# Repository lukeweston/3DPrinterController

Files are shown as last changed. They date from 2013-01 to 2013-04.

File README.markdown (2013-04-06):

3D printer / CNC machine controller:   

The final system will be broken across three boards, to allow for modularity, replacement of the modules individually, upgradability, and to allow enough space for proper
design of the power electronics.   

a) Microcontroller, UI, storage, display, connectivity etc.   
b) Power distribution, switching, heater control etc.   
c) Stepper motor drivers.   

Example image of 5-channel stepper motor controller board:   

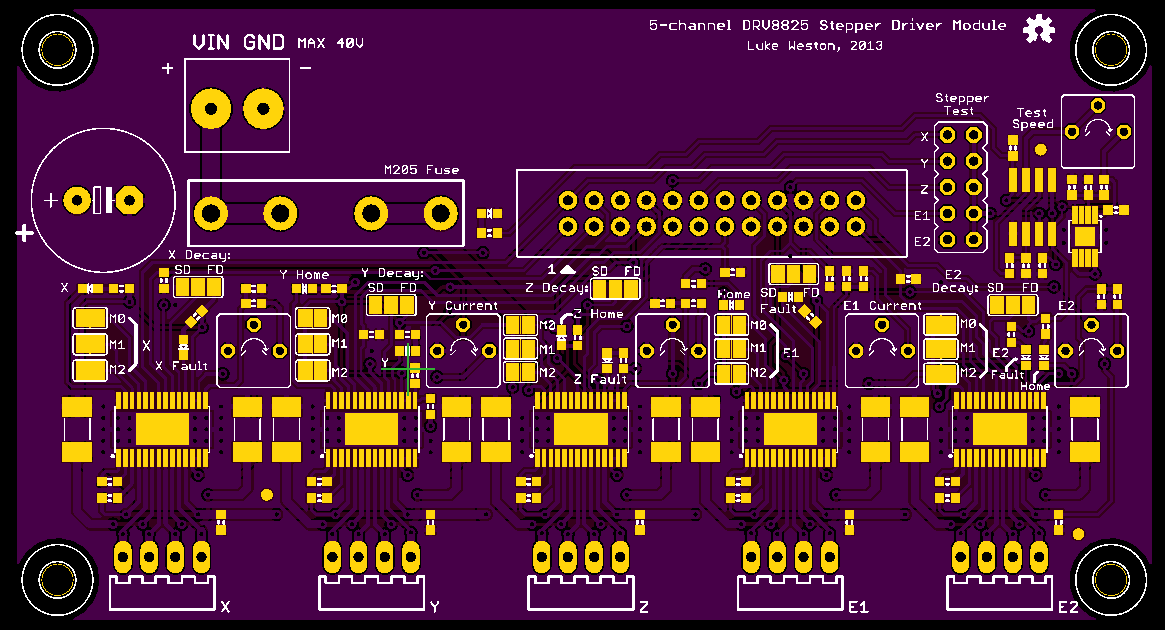
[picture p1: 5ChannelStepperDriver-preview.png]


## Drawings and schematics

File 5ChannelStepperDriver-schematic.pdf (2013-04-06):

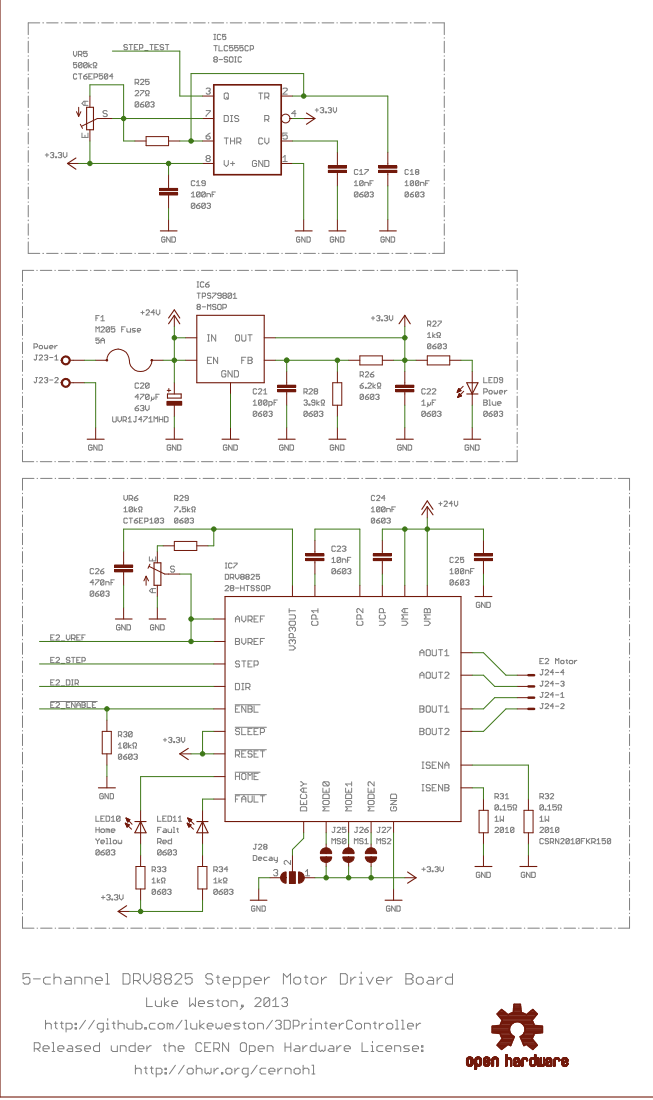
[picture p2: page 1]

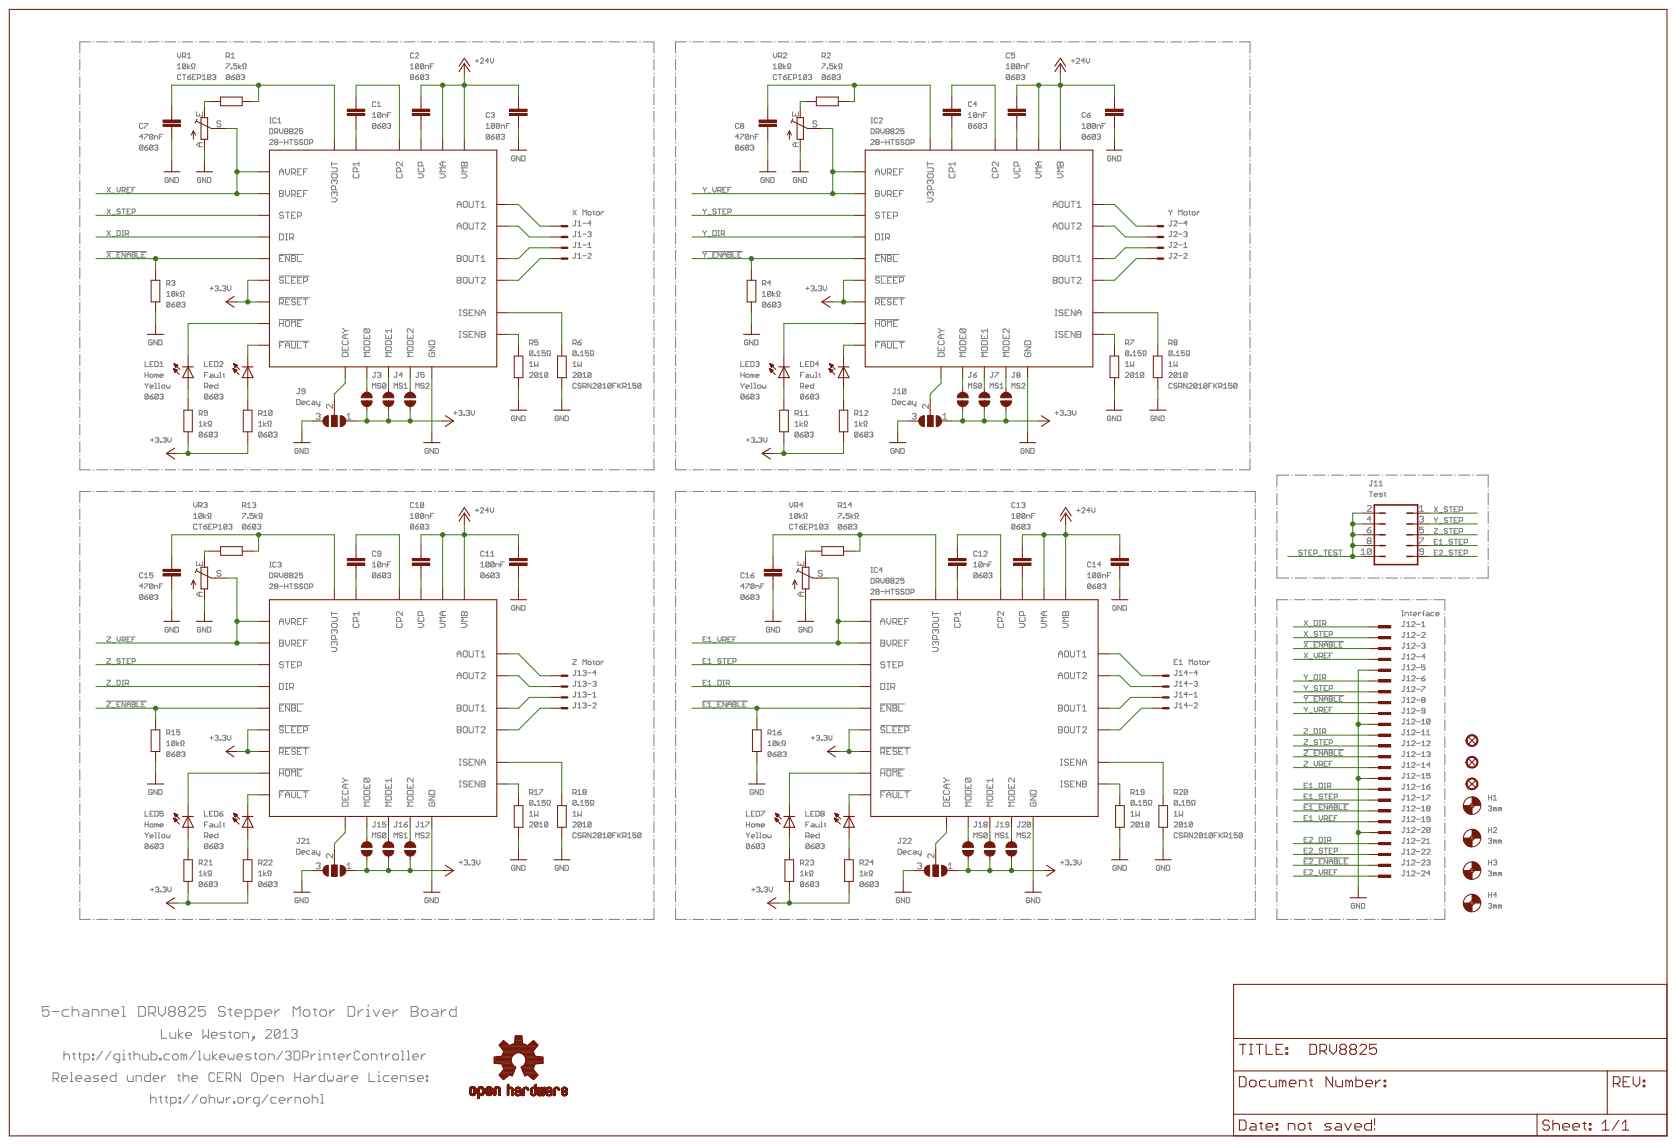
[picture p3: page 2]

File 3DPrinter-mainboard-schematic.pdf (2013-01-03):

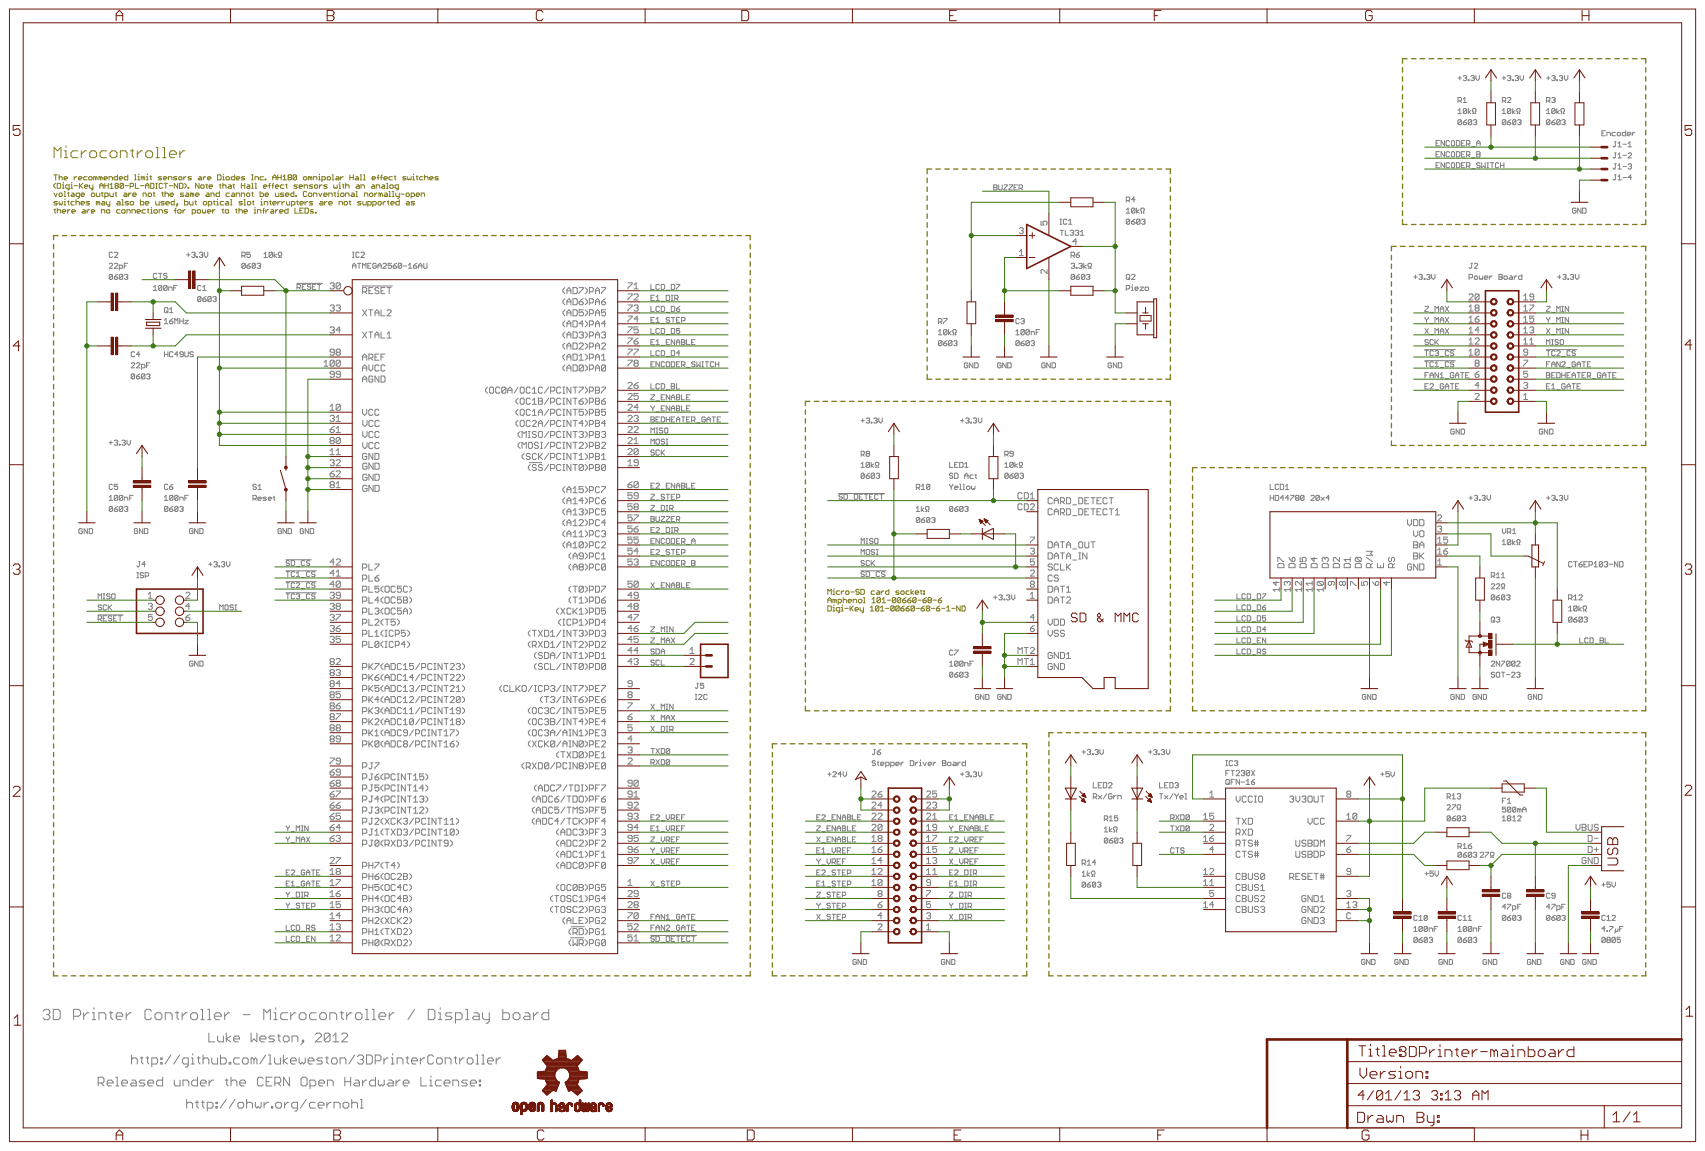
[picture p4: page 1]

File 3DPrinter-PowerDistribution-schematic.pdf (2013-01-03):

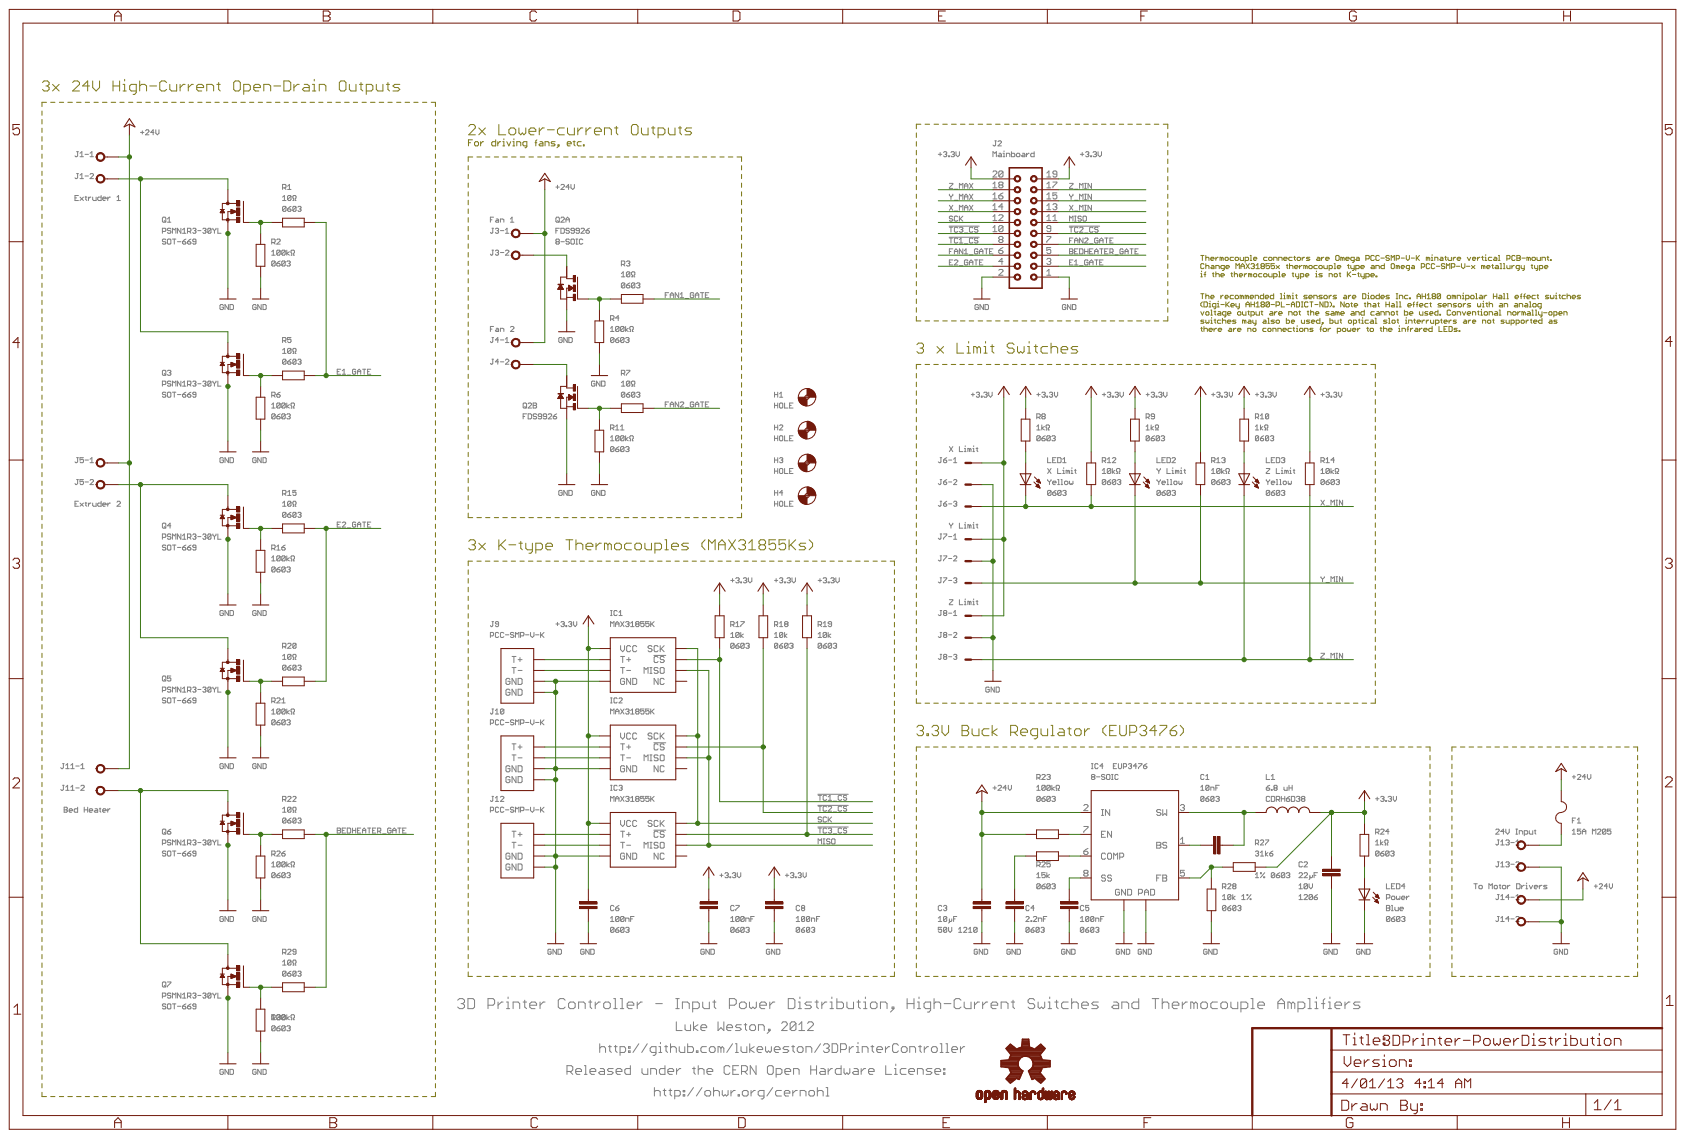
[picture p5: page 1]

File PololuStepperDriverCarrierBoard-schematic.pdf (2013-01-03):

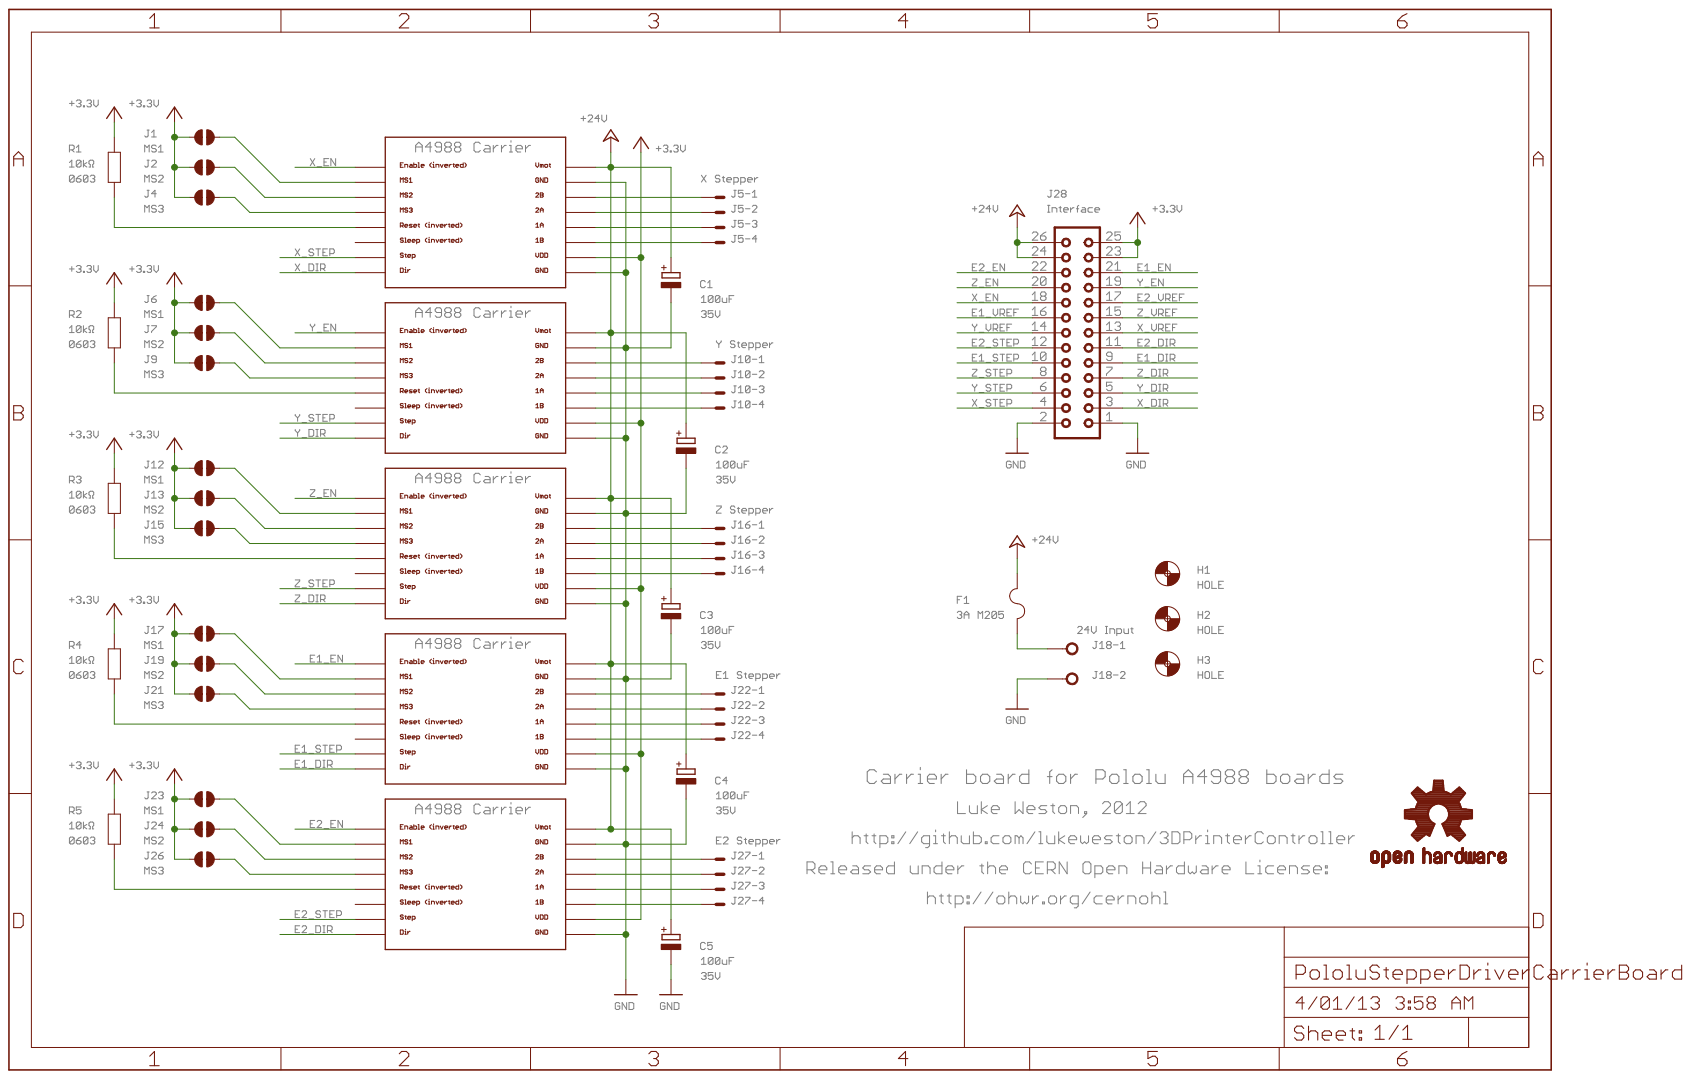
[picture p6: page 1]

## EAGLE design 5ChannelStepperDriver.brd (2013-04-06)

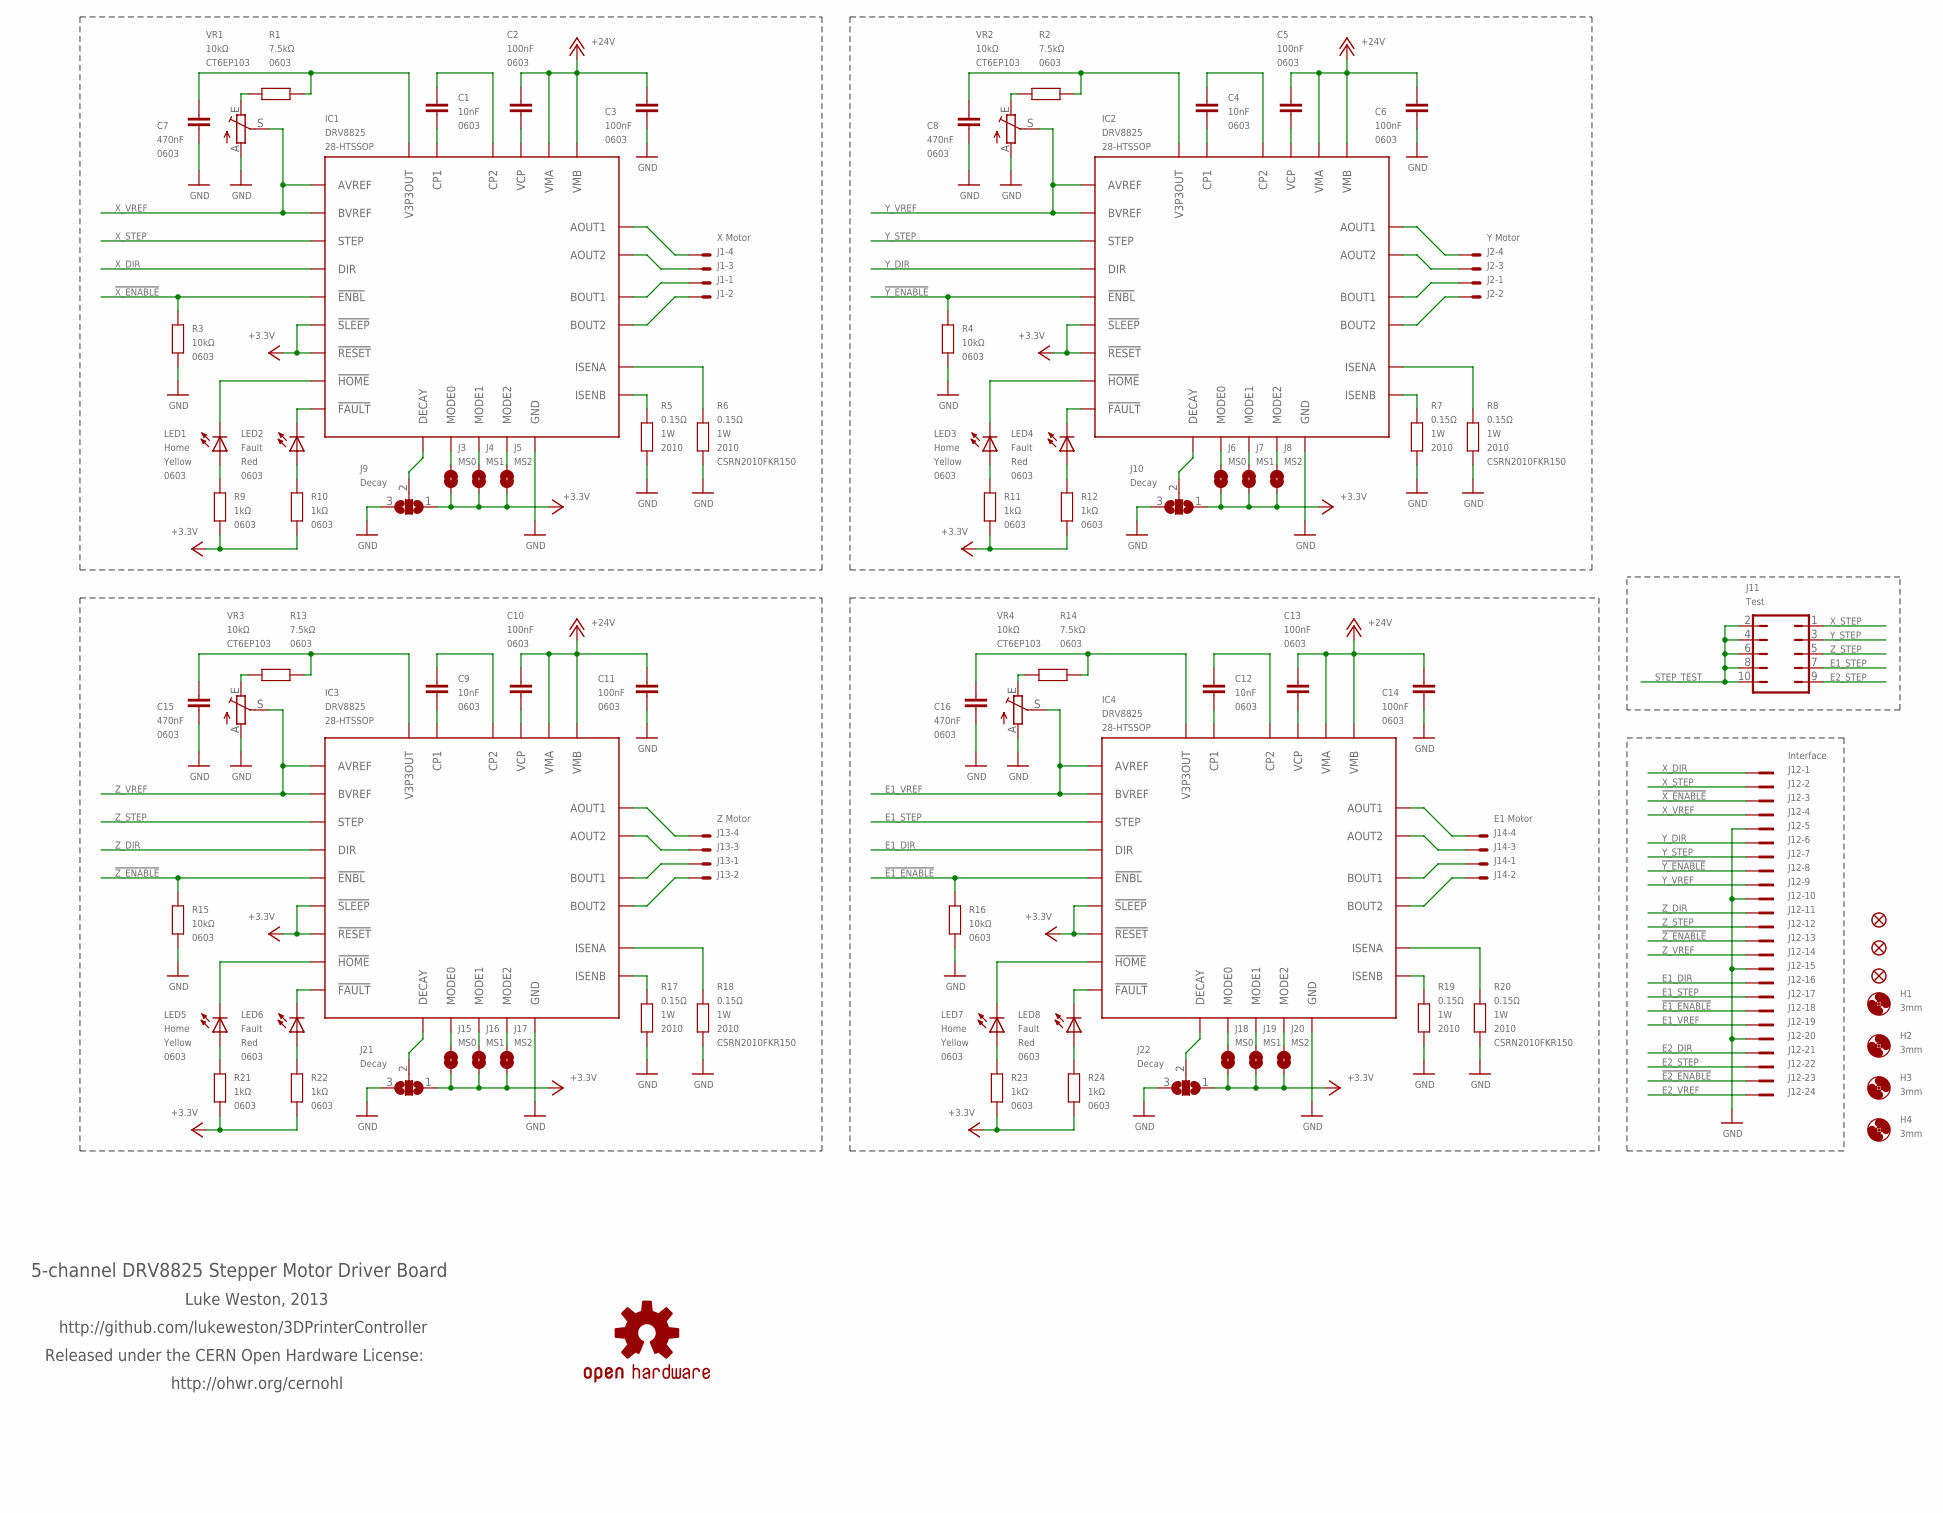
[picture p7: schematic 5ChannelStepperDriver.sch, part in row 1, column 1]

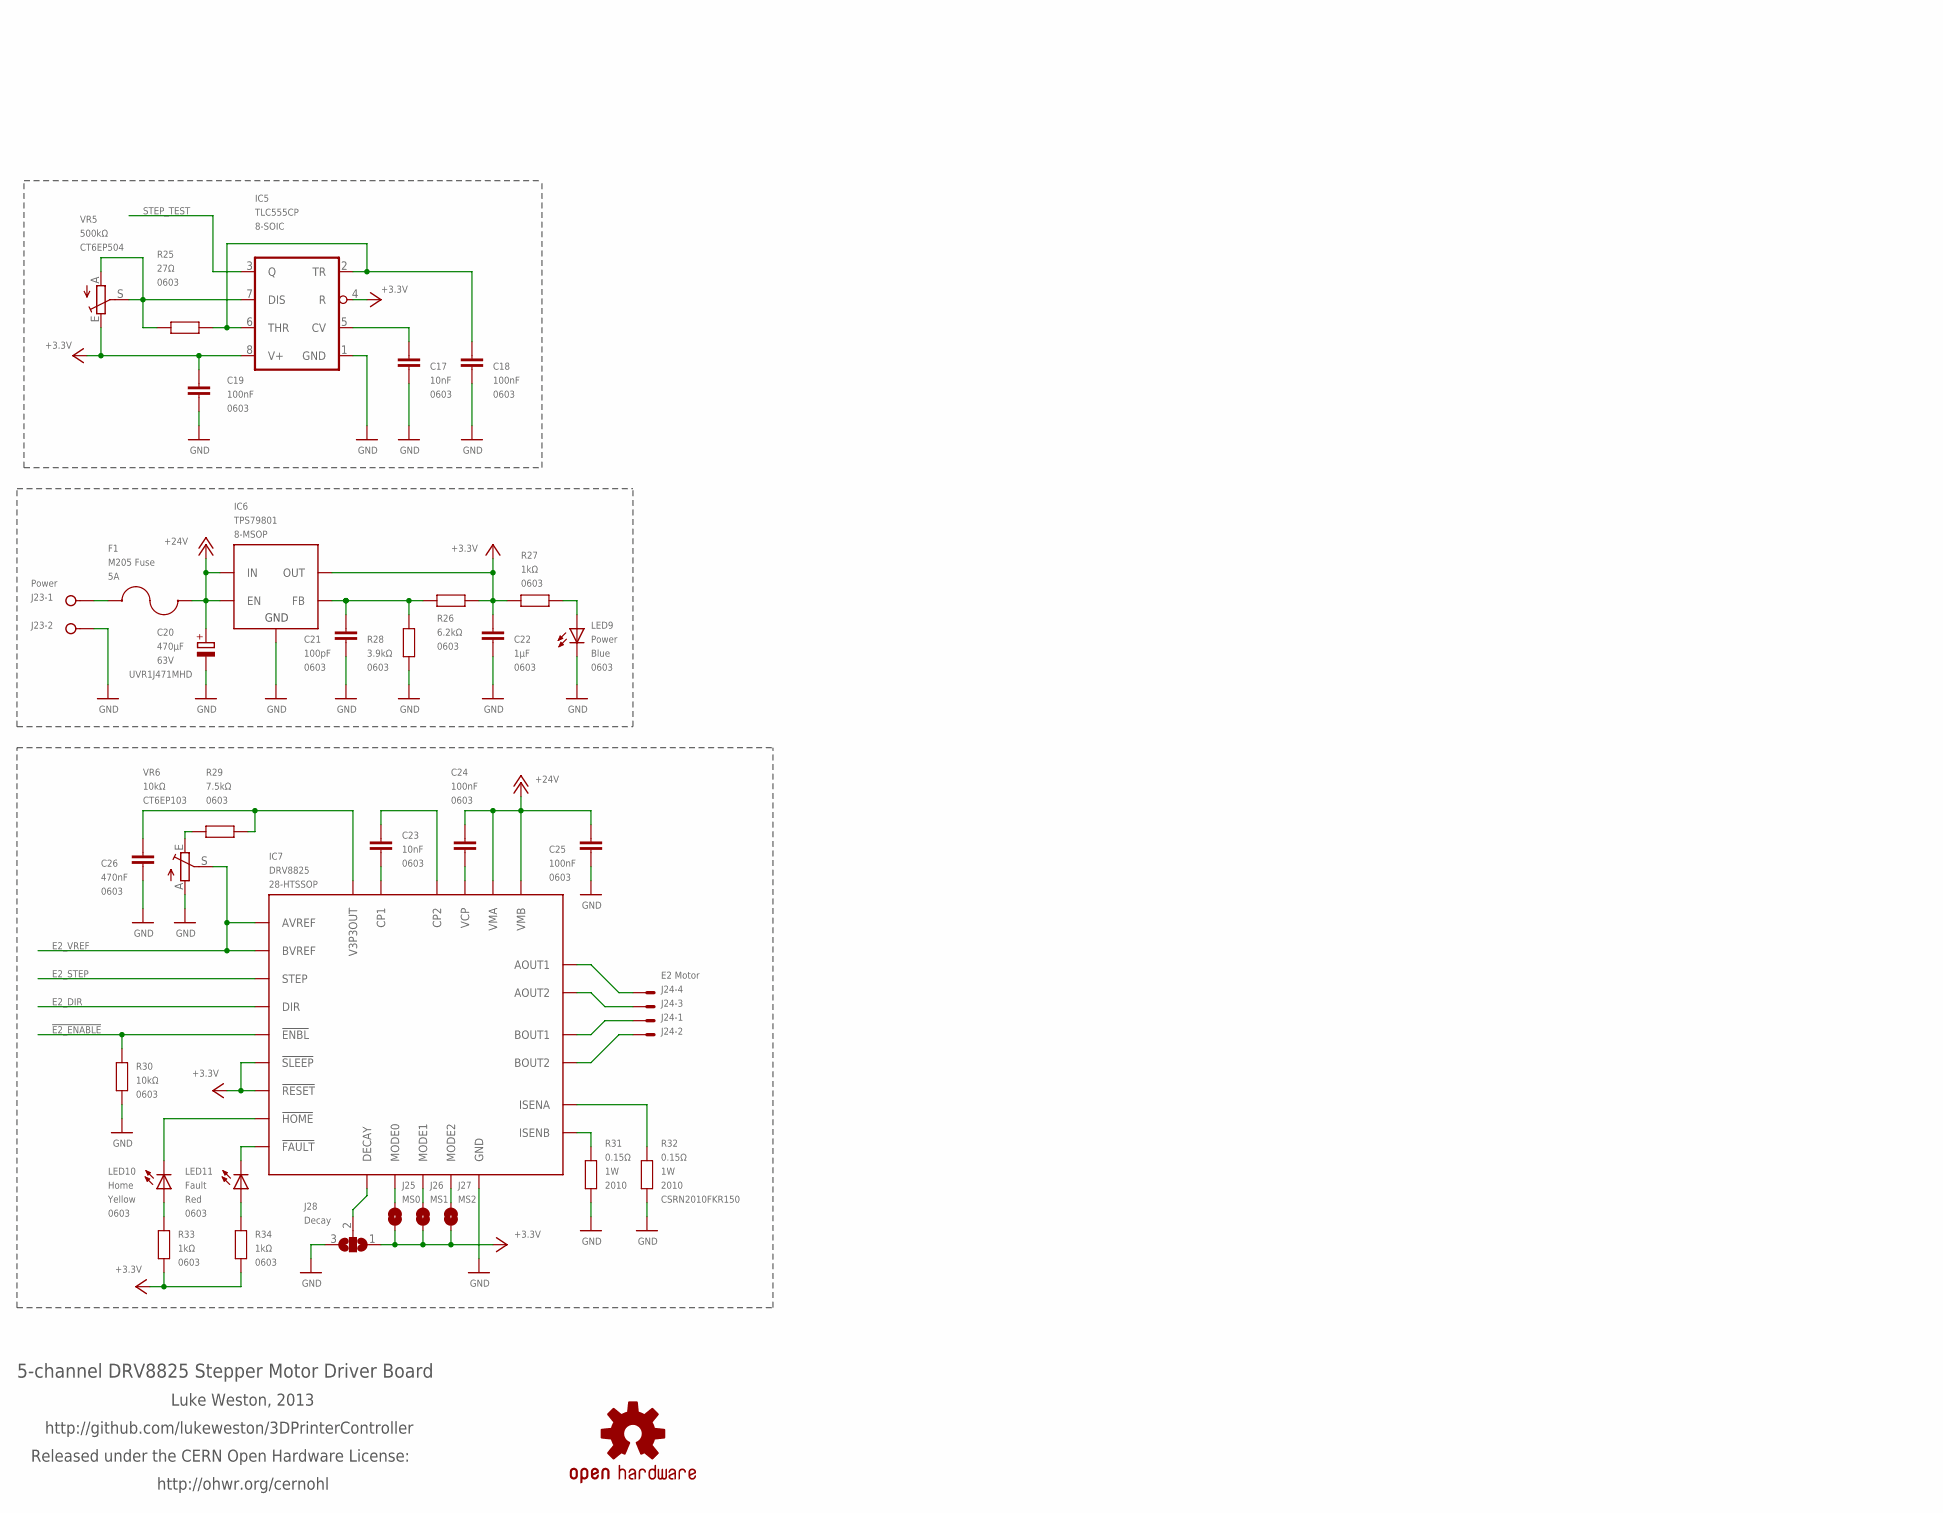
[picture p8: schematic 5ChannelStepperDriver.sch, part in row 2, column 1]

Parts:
C1, C4, C9, C12, C17, C23: 10nF; 0603
C2, C3, C5, C6, C10, C11, C13, C14, C18, C19, C24, C25: 100nF; 0603
C7, C8, C15, C16, C26: 470nF; 0603
C20: 470µF; E5-13; VOLTAGE 63V
C21: 100pF; 0603
C22: 1µF; 0603
F1: M205 Fuse; FUSECLIP-FC211
H1, H2, H3, H4: 3mm; 3,0
IC1, IC2, IC3, IC4, IC7: DRV8825; R-PDSO-G28
IC5: TLC555CP; SO08
IC6: TPS79801; R-PDSO-G8
J1: X Motor; 7395-04
J2: Y Motor; 7395-04
J3, J6, J15, J18, J25: MS0; SJ
J4, J7, J16, J19, J26: MS1; SJ
J5, J8, J17, J20, J27: MS2; SJ
J9, J10, J21, J22, J28: Decay; SJ_2
J11: Test; JP5Q
J12: Interface; PAK100/2500-24
J13: Z Motor; 7395-04
J14: E1 Motor; 7395-04
J23: Power; W237-132
J24: E2 Motor; 7395-04
JP1, JP2, JP3: FIDUCIAL1X2; FIDUCIAL-1X2
LED1, LED3, LED5, LED7, LED10: Home; LED-0603
LED2, LED4, LED6, LED8, LED11: Fault; LED-0603
LED9: Power; LED-0603
R1, R2, R13, R14, R29: 7.5kΩ; 0603
R3, R4, R15, R16, R30: 10kΩ; 0603
R5, R6, R7, R8, R17, R18, R19, R20, R31, R32: 0.15Ω; R2010
R9, R10, R11, R12, R21, R22, R23, R24, R27, R33, R34: 1kΩ; 0603
R25: 27Ω; 0603
R26: 6.2kΩ; 0603
R28: 3.9kΩ; 0603
SY1, SY2: OSHW-LOGOS; OSHW-LOGO-S
VR1, VR2, VR3, VR4, VR6: 10kΩ; CT6
VR5: 500kΩ; CT6

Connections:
!E1_ENABLE: IC4.21 (!ENBL), J12.18, R16.1
!E2_ENABLE: IC7.21 (!ENBL), J12.23, R30.1
!X_ENABLE: IC1.21 (!ENBL), J12.3, R3.1
!Y_ENABLE: IC2.21 (!ENBL), J12.8, R4.1
!Z_ENABLE: IC3.21 (!ENBL), J12.13, R15.1
+3V3: C19.1, C22.1, IC1.16 (!RESET), IC1.17 (!SLEEP), IC2.16 (!RESET), IC2.17 (!SLEEP), IC3.16 (!RESET), IC3.17 (!SLEEP), IC4.16 (!RESET), IC4.17 (!SLEEP), IC5.4 (R), IC5.8 (V+), IC6.1 (OUT), IC7.16 (!RESET), IC7.17 (!SLEEP), J3.1, J4.1, J5.1, J6.1, J7.1, J8.1, J9.1, J10.1, J15.1, J16.1, J17.1, J18.1, J19.1, J20.1, J21.1, J22.1, J25.1, J26.1, J27.1, J28.1, R9.2, R10.2, R11.2, R12.2, R21.2, R22.2, R23.2, R24.2, R26.2, R27.2, R33.2, R34.2, VR5.E
+24V: C2.1, C3.1, C5.1, C6.1, C10.1, C11.1, C13.1, C14.1, C20.+, C24.1, C25.1, F1.3 (2), F1.4 (2), IC1.4 (VMA), IC1.11 (VMB), IC2.4 (VMA), IC2.11 (VMB), IC3.4 (VMA), IC3.11 (VMB), IC4.4 (VMA), IC4.11 (VMB), IC6.5 (EN), IC6.8 (IN), IC7.4 (VMA), IC7.11 (VMB)
E1_DIR: IC4.20 (DIR), J12.16
E1_STEP: IC4.22 (STEP), J11.7, J12.17
E1_VREF: IC4.12 (AVREF), IC4.13 (BVREF), J12.19, VR4.S
E2_DIR: IC7.20 (DIR), J12.21
E2_STEP: IC7.22 (STEP), J11.9, J12.22
E2_VREF: IC7.12 (AVREF), IC7.13 (BVREF), J12.24, VR6.S
GND: C3.2, C6.2, C7.2, C8.2, C11.2, C14.2, C15.2, C16.2, C17.2, C18.2, C19.2, C20.-, C21.2, C22.2, C25.2, C26.2, IC1.14 (GND), IC1.28 (GND), IC1.PAD (GND), IC2.14 (GND), IC2.28 (GND), IC2.PAD (GND), IC3.14 (GND), IC3.28 (GND), IC3.PAD (GND), IC4.14 (GND), IC4.28 (GND), IC4.PAD (GND), IC5.1 (GND), IC6.4 (GND), IC6.PAD (GND), IC7.14 (GND), IC7.28 (GND), IC7.PAD (GND), J9.3, J10.3, J12.5, J12.10, J12.15, J12.20, J21.3, J22.3, J23.2, J28.3, LED9.C, R3.2, R4.2, R5.2, R6.2, R7.2, R8.2, R15.2, R16.2, R17.2, R18.2, R19.2, R20.2, R28.2, R30.2, R31.2, R32.2, VR1.A, VR2.A, VR3.A, VR4.A, VR6.A
unnamed: IC1.5 (AOUT1), J1.4
unnamed: IC4.10 (BOUT1), J14.1
unnamed: IC3.10 (BOUT1), J13.1
unnamed: IC7.10 (BOUT1), J24.1
unnamed: IC7.7 (AOUT2), J24.3
unnamed: C7.1, IC1.15 (V3P3OUT), R1.1
unnamed: F1.1, F1.2 (1), J23.1
unnamed: R14.2, VR4.E
unnamed: C8.1, IC2.15 (V3P3OUT), R2.1
unnamed: C16.1, IC4.15 (V3P3OUT), R14.1
unnamed: C26.1, IC7.15 (V3P3OUT), R29.1
unnamed: R2.2, VR2.E
unnamed: R29.2, VR6.E
unnamed: R1.2, VR1.E
unnamed: C18.1, IC5.2 (TR), IC5.6 (THR), R25.1
unnamed: C15.1, IC3.15 (V3P3OUT), R13.1
unnamed: C21.1, IC6.2 (FB), R26.1, R28.1
unnamed: R13.2, VR3.E
unnamed: C17.1, IC5.5 (CV)
unnamed: LED9.A, R27.1
unnamed: IC5.7 (DIS), R25.2, VR5.A, VR5.S
unnamed: IC1.7 (AOUT2), J1.3
unnamed: IC1.10 (BOUT1), J1.1
unnamed: IC1.8 (BOUT2), J1.2
unnamed: C1.2, IC1.1 (CP1)
unnamed: C1.1, IC1.2 (CP2)
unnamed: IC1.19 (DECAY), J9.2
unnamed: C2.2, IC1.3 (VCP)
unnamed: IC1.6 (ISENA), R6.1
unnamed: IC3.5 (AOUT1), J13.4
unnamed: IC1.9 (ISENB), R5.1
unnamed: IC3.7 (AOUT2), J13.3
unnamed: IC3.8 (BOUT2), J13.2
unnamed: IC1.18 (!FAULT), LED2.C
unnamed: IC1.27 (!HOME), LED1.C
unnamed: LED1.A, R9.1
unnamed: LED2.A, R10.1
unnamed: IC1.25 (MODE1), J4.2
unnamed: IC1.26 (MODE2), J5.2
unnamed: IC1.24 (MODE0), J3.2
unnamed: C10.2, IC3.3 (VCP)
unnamed: IC3.6 (ISENA), R18.1
unnamed: IC3.9 (ISENB), R17.1
unnamed: IC3.18 (!FAULT), LED6.C
unnamed: IC3.27 (!HOME), LED5.C
unnamed: LED5.A, R21.1
unnamed: LED6.A, R22.1
unnamed: C9.2, IC3.1 (CP1)
unnamed: C9.1, IC3.2 (CP2)
unnamed: IC3.19 (DECAY), J21.2
unnamed: IC3.24 (MODE0), J15.2
unnamed: IC3.25 (MODE1), J16.2
unnamed: IC3.26 (MODE2), J17.2
unnamed: IC2.5 (AOUT1), J2.4
unnamed: IC2.7 (AOUT2), J2.3
unnamed: IC2.10 (BOUT1), J2.1
unnamed: IC2.8 (BOUT2), J2.2
unnamed: C5.2, IC2.3 (VCP)
unnamed: IC2.6 (ISENA), R8.1
unnamed: IC2.9 (ISENB), R7.1
unnamed: IC2.18 (!FAULT), LED4.C
unnamed: IC2.27 (!HOME), LED3.C
unnamed: LED3.A, R11.1
unnamed: LED4.A, R12.1
unnamed: C4.2, IC2.1 (CP1)
unnamed: C4.1, IC2.2 (CP2)
unnamed: IC2.19 (DECAY), J10.2
unnamed: IC2.24 (MODE0), J6.2
unnamed: IC2.25 (MODE1), J7.2
unnamed: IC2.26 (MODE2), J8.2
unnamed: IC4.5 (AOUT1), J14.4
unnamed: IC4.7 (AOUT2), J14.3
unnamed: IC4.8 (BOUT2), J14.2
unnamed: C13.2, IC4.3 (VCP)
unnamed: IC4.6 (ISENA), R20.1
unnamed: IC4.9 (ISENB), R19.1
unnamed: IC4.18 (!FAULT), LED8.C
unnamed: IC4.27 (!HOME), LED7.C
unnamed: LED7.A, R23.1
unnamed: LED8.A, R24.1
unnamed: C12.2, IC4.1 (CP1)
unnamed: C12.1, IC4.2 (CP2)
unnamed: IC4.19 (DECAY), J22.2
unnamed: IC4.24 (MODE0), J18.2
unnamed: IC4.25 (MODE1), J19.2
unnamed: IC4.26 (MODE2), J20.2
unnamed: IC7.5 (AOUT1), J24.4
unnamed: IC7.8 (BOUT2), J24.2
unnamed: C24.2, IC7.3 (VCP)
unnamed: IC7.6 (ISENA), R32.1
unnamed: IC7.9 (ISENB), R31.1
unnamed: IC7.18 (!FAULT), LED11.C
unnamed: IC7.27 (!HOME), LED10.C
unnamed: LED10.A, R33.1
unnamed: LED11.A, R34.1
unnamed: C23.2, IC7.1 (CP1)
unnamed: C23.1, IC7.2 (CP2)
unnamed: IC7.19 (DECAY), J28.2
unnamed: IC7.24 (MODE0), J25.2
unnamed: IC7.25 (MODE1), J26.2
unnamed: IC7.26 (MODE2), J27.2
STEP_TEST: IC5.3 (Q), J11.2, J11.4, J11.6, J11.8, J11.10
X_DIR: IC1.20 (DIR), J12.1
X_STEP: IC1.22 (STEP), J11.1, J12.2
X_VREF: IC1.12 (AVREF), IC1.13 (BVREF), J12.4, VR1.S
Y_DIR: IC2.20 (DIR), J12.6
Y_STEP: IC2.22 (STEP), J11.3, J12.7
Y_VREF: IC2.12 (AVREF), IC2.13 (BVREF), J12.9, VR2.S
Z_DIR: IC3.20 (DIR), J12.11
Z_STEP: IC3.22 (STEP), J11.5, J12.12
Z_VREF: IC3.12 (AVREF), IC3.13 (BVREF), J12.14, VR3.S

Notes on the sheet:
5-channel DRV8825 Stepper Motor Driver Board
Luke Weston, 2013
http://github.com/lukeweston/3DPrinterController
Released under the CERN Open Hardware License:
http://ohwr.org/cernohl

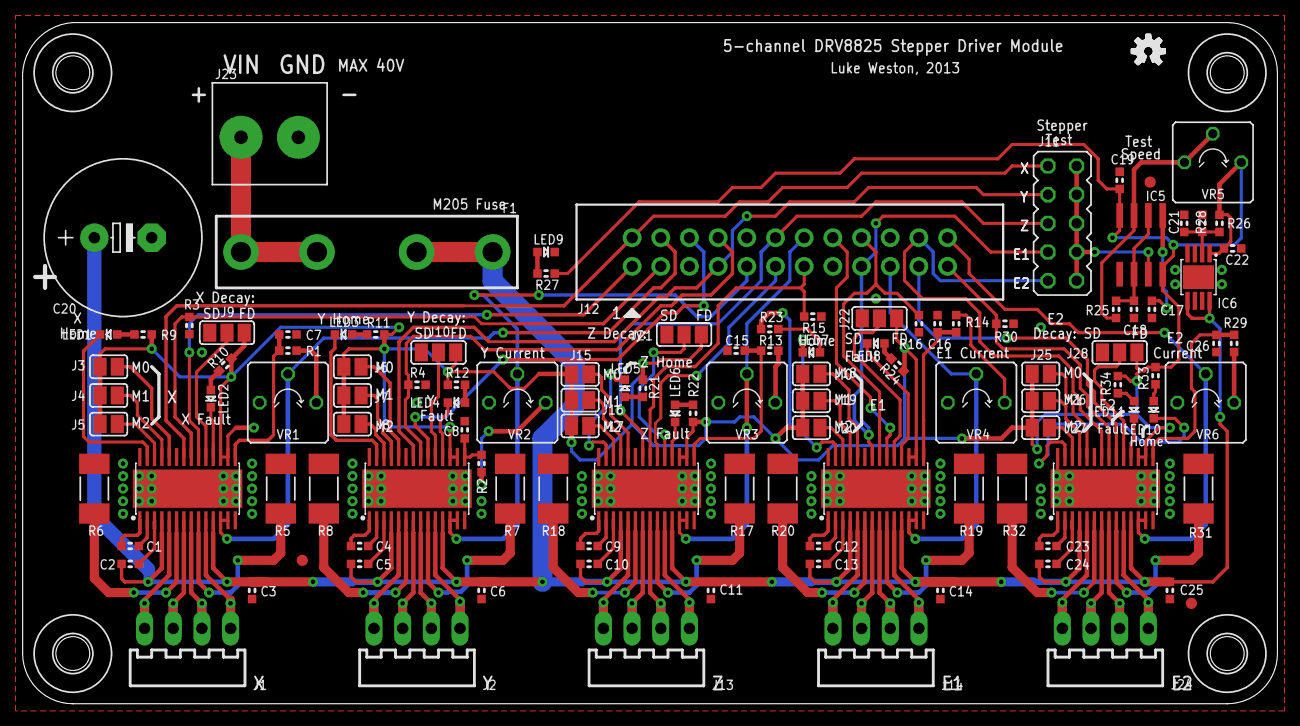
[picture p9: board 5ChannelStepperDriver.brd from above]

Board: 2 copper layers, 111.1 x 60.3 mm, 122 parts (0 on the bottom side), 125 nets.

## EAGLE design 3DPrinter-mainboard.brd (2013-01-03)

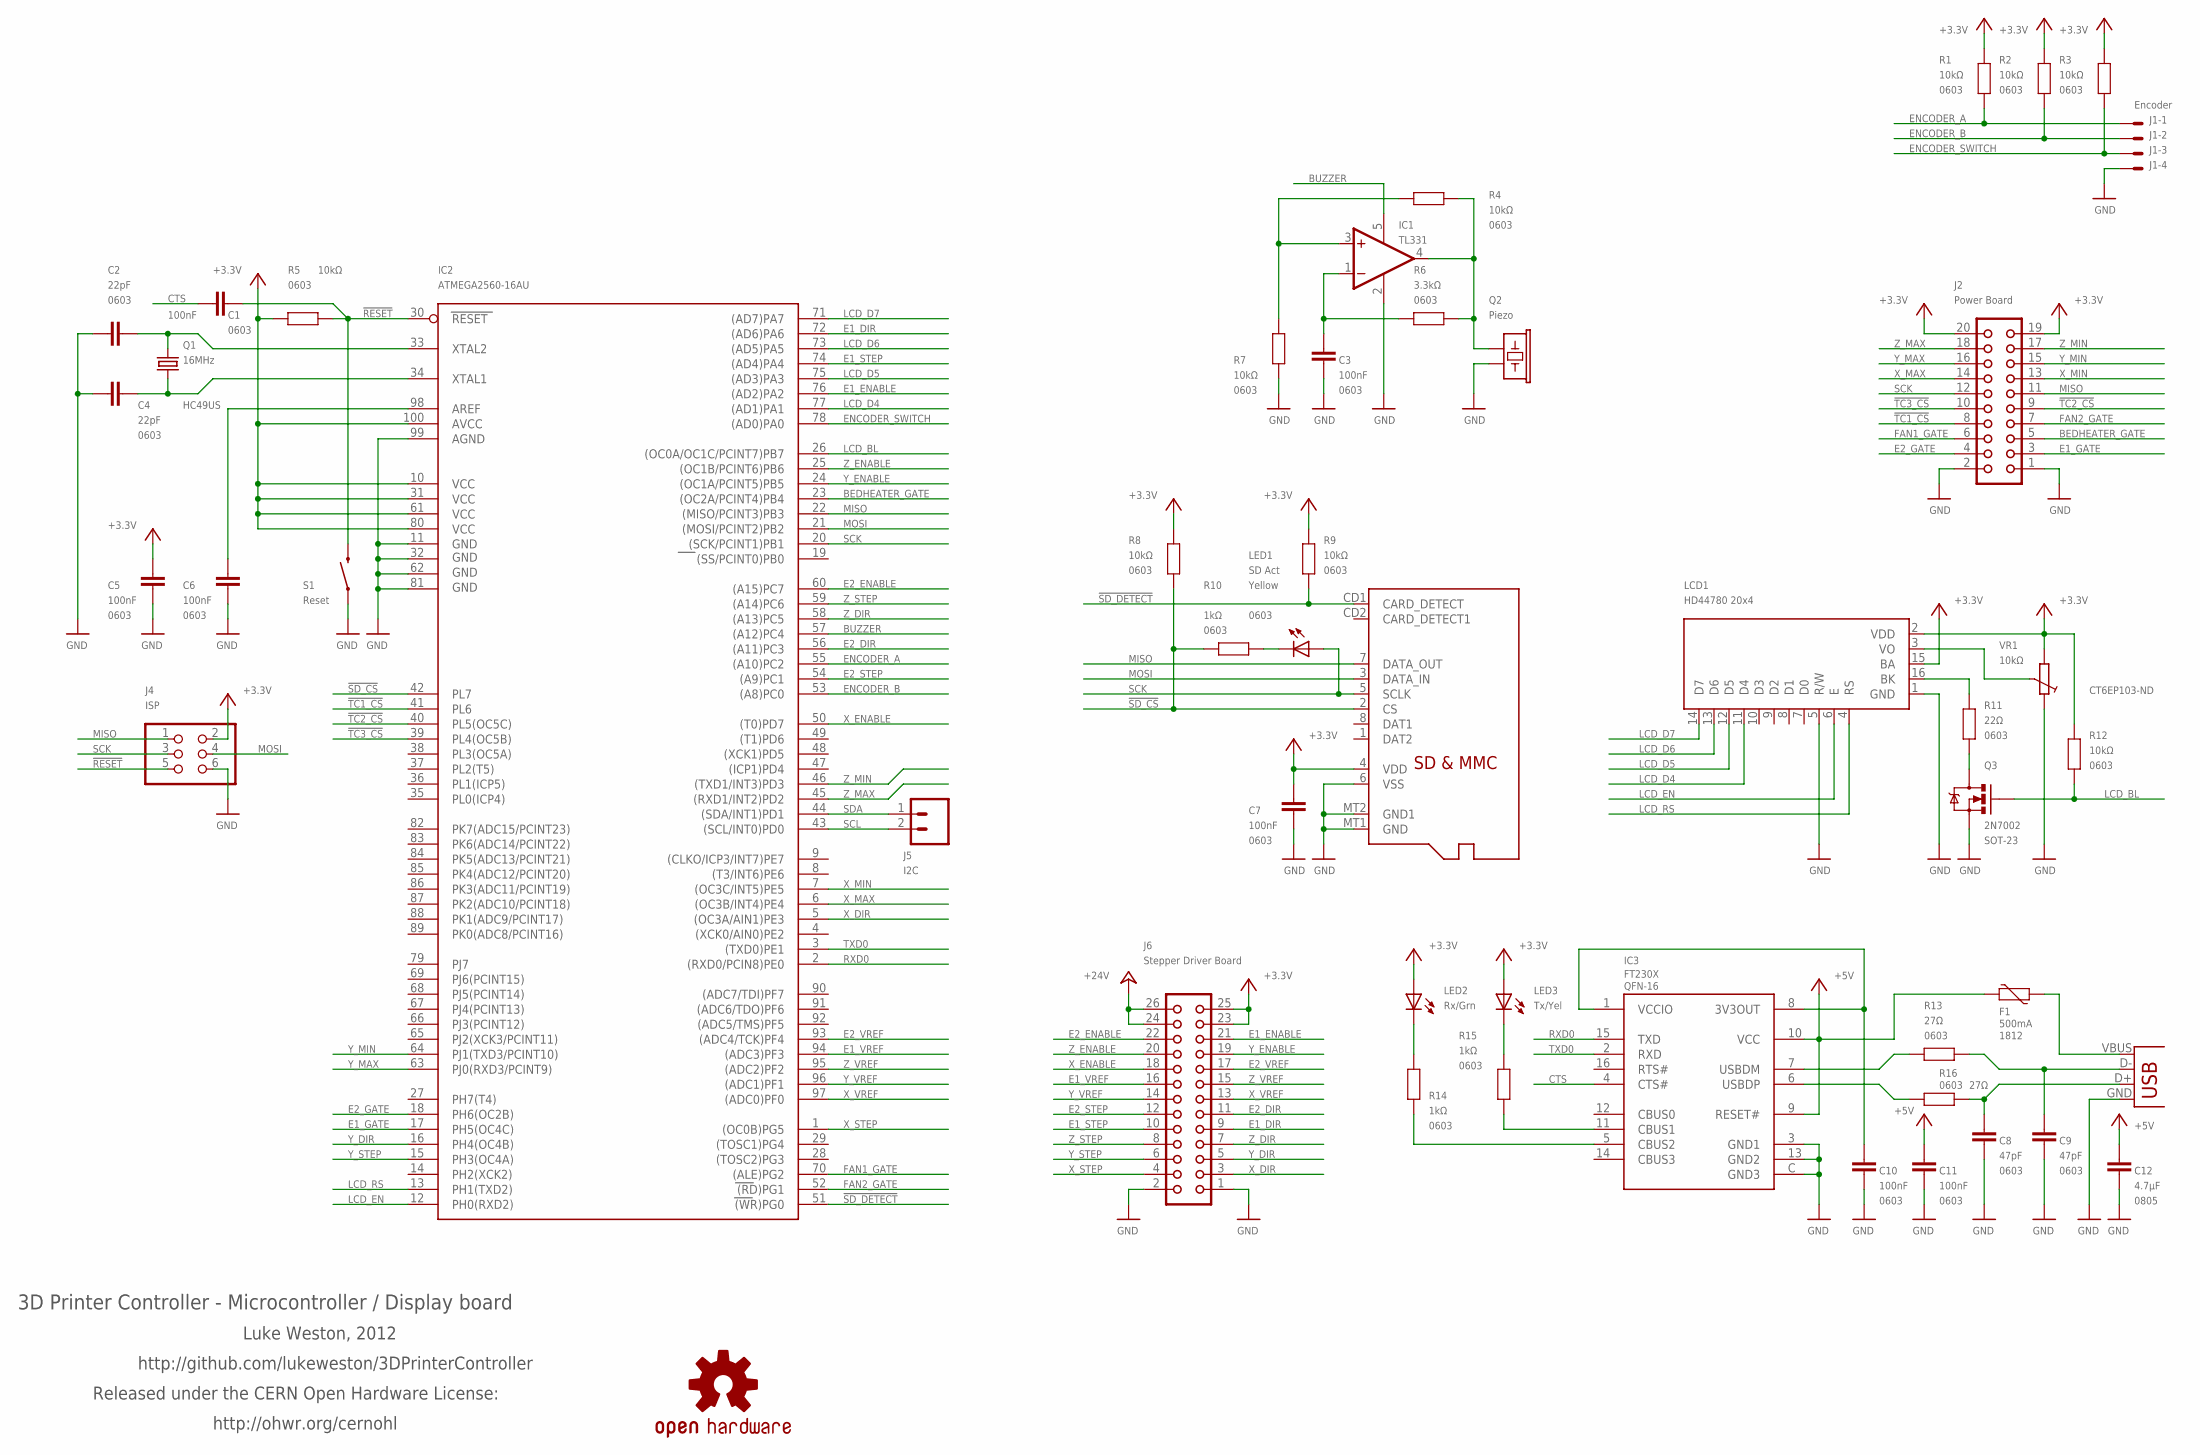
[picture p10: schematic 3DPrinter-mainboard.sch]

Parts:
C1, C3, C5, C6, C7, C10, C11: 100nF; 0603
C2, C4: 22pF; 0603
C8, C9: 47pF; 0603
C12: 4.7µF; 0805
F1: 500mA; 1812
IC1: TL331; DBV-R-PDSO-G5
IC2: ATMEGA2560-16AU; TQFP100
IC3: FT230X; QFN4X4-16
J1: Encoder; 7395-04
J2: Power Board; CON20L
J3: MicroSD Card; ADAFRUIT_MICROSD
J4: ISP; 2X03
J5: I2C; 1X02
J6: Stepper Driver Board; CON26L
LCD1: HD44780 20x4; HDM20416L
LED1: SD Act; LED-0603
LED2: Rx/Grn; LED-0603
LED3: Tx/Yel; LED-0603
Q1: 16MHz; HC49US
Q2: Piezo; FREETRONICS-MASTER-V1_BUZZER-12X12-SMT
Q3: 2N7002; SOT23-3
R1, R2, R3, R4, R5, R7, R8, R9, R12: 10kΩ; 0603
R6: 3.3kΩ; 0603
R10, R14, R15: 1kΩ; 0603
R11: 22Ω; 0603
R13, R16: 27Ω; 0603
S1: Reset; TACTILE_SWITCH_SMD
SY: OSHW-LOGOS; OSHW-LOGO-S
VR1: 10kΩ; CT6
X1: USB-MICROB

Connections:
!RESET: C1.2, IC2.30 (RESET), J4.5, R5.2, S1.3 (2)
!SD_CS: IC2.42 (PL7), J3.2 (CS), R8.2, R10.2
!SD_DETECT: IC2.51 ((WR)PG0), J3.CD1 (CARD_DETECT), R9.2
!TC1_CS: IC2.41 (PL6), J2.8
!TC2_CS: IC2.40 (PL5(OC5C)), J2.9
!TC3_CS: IC2.39 (PL4(OC5B)), J2.10
+3V3: C5.1, C7.1, IC2.10 (VCC), IC2.31 (VCC1), IC2.61 (VCC2), IC2.80 (VCC3), IC2.100 (AVCC), J2.19, J2.20, J3.4 (VDD), J4.2, J6.23, J6.25, LCD1.2 (VDD), LCD1.15 (BA), LED2.A, LED3.A, R1.1, R2.1, R3.1, R5.1, R8.1, R9.1, R12.1, VR1.A
+5V: C11.1, C12.1, F1.2, IC3.9 (RESET#), IC3.10 (VCC)
+24V: J6.24, J6.26
BEDHEATER_GATE: IC2.23 ((OC2A/PCINT4)PB4), J2.5
BUZZER: IC1.5 (V+), IC2.57 ((A12)PC4)
CTS: C1.1, IC3.4 (CTS#)
E1_DIR: IC2.72 ((AD6)PA6), J6.9
E1_ENABLE: IC2.76 ((AD2)PA2), J6.21
E1_GATE: IC2.17 (PH5(OC4C)), J2.3
E1_STEP: IC2.74 ((AD4)PA4), J6.10
E1_VREF: IC2.94 ((ADC3)PF3), J6.16
E2_DIR: IC2.56 ((A11)PC3), J6.11
E2_ENABLE: IC2.60 ((A15)PC7), J6.22
E2_GATE: IC2.18 (PH6(OC2B)), J2.4
E2_STEP: IC2.54 ((A9)PC1), J6.12
E2_VREF: IC2.93 ((ADC4/TCK)PF4), J6.17
ENCODER_A: IC2.55 ((A10)PC2), J1.1, R1.2
ENCODER_B: IC2.53 ((A8)PC0), J1.2, R2.2
ENCODER_SWITCH: IC2.78 ((AD0)PA0), J1.3, R3.2
FAN1_GATE: IC2.70 ((ALE)PG2), J2.6
FAN2_GATE: IC2.52 ((RD)PG1), J2.7
GND: C2.1, C3.2, C4.1, C5.2, C6.2, C7.2, C8.2, C9.2, C10.2, C11.2, C12.2, IC1.2 (GND), IC2.11 (GND), IC2.32 (GND1), IC2.62 (GND2), IC2.81 (GND3), IC2.99 (AGND), IC3.3 (GND1), IC3.13 (GND2), IC3.C (GND3), J1.4, J2.1, J2.2, J3.6 (VSS), J3.MT1 (GND), J3.MT2 (GND1), J4.6, J6.1, J6.2, LCD1.1 (GND), LCD1.5 (R/W), Q2.1, Q3.2 (S), R7.1, S1.1, VR1.E, X1.GND
LCD_BL: IC2.26 ((OC0A/OC1C/PCINT7)PB7), Q3.1 (G), R12.2
LCD_D4: IC2.77 ((AD1)PA1), LCD1.11 (D4)
LCD_D5: IC2.75 ((AD3)PA3), LCD1.12 (D5)
LCD_D6: IC2.73 ((AD5)PA5), LCD1.13 (D6)
LCD_D7: IC2.71 ((AD7)PA7), LCD1.14 (D7)
LCD_EN: IC2.12 (PH0(RXD2)), LCD1.6 (E)
LCD_RS: IC2.13 (PH1(TXD2)), LCD1.4 (RS)
MISO: IC2.22 ((MISO/PCINT3)PB3), J2.11, J3.7 (DATA_OUT), J4.1
MOSI: IC2.21 ((MOSI/PCINT2)PB2), J3.3 (DATA_IN), J4.4
unnamed: LCD1.16 (BK), R11.1
unnamed: LED3.C, R15.1
unnamed: Q3.3 (D), R11.2
unnamed: IC3.7 (USBDM), R13.1
unnamed: C2.2, IC2.33 (XTAL2), Q1.2
unnamed: IC3.11 (CBUS1), R15.2
unnamed: LED2.C, R14.1
unnamed: IC3.5 (CBUS2), R14.2
unnamed: LED1.C, R10.1
unnamed: C3.1, IC1.1 (-IN), R6.2
unnamed: IC1.3 (+IN), R4.2, R7.2
unnamed: IC1.4 (OUT), Q2.2, R4.1, R6.1
unnamed: C4.2, IC2.34 (XTAL1), Q1.1
unnamed: C10.1, IC3.1 (VCCIO), IC3.8 (3V3OUT)
unnamed: C6.1, IC2.98 (AREF)
unnamed: IC3.6 (USBDP), R16.1
unnamed: C8.1, R16.2, X1.D+
unnamed: C9.1, R13.2, X1.D-
unnamed: F1.1, X1.VBUS
unnamed: LCD1.3 (VO), VR1.S
RXD0: IC2.2 ((RXD0/PCIN8)PE0), IC3.15 (TXD)
SCK: IC2.20 ((SCK/PCINT1)PB1), J2.12, J3.5 (SCLK), J4.3, LED1.A
SCL: IC2.43 ((SCL/INT0)PD0), J5.2
SDA: IC2.44 ((SDA/INT1)PD1), J5.1
TXD0: IC2.3 ((TXD0)PE1), IC3.2 (RXD)
X_DIR: IC2.5 ((OC3A/AIN1)PE3), J6.3
X_ENABLE: IC2.50 ((T0)PD7), J6.18
X_MAX: IC2.6 ((OC3B/INT4)PE4), J2.14
X_MIN: IC2.7 ((OC3C/INT5)PE5), J2.13
X_STEP: IC2.1 ((OC0B)PG5), J6.4
X_VREF: IC2.97 ((ADC0)PF0), J6.13
Y_DIR: IC2.16 (PH4(OC4B)), J6.5
Y_ENABLE: IC2.24 ((OC1A/PCINT5)PB5), J6.19
Y_MAX: IC2.63 (PJ0(RXD3/PCINT9)), J2.16
Y_MIN: IC2.64 (PJ1(TXD3/PCINT10)), J2.15
Y_STEP: IC2.15 (PH3(OC4A)), J6.6
Y_VREF: IC2.96 ((ADC1)PF1), J6.14
Z_DIR: IC2.58 ((A13)PC5), J6.7
Z_ENABLE: IC2.25 ((OC1B/PCINT6)PB6), J6.20
Z_MAX: IC2.45 ((RXD1/INT2)PD2), J2.18
Z_MIN: IC2.46 ((TXD1/INT3)PD3), J2.17
Z_STEP: IC2.59 ((A14)PC6), J6.8
Z_VREF: IC2.95 ((ADC2)PF2), J6.15

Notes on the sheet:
3D Printer Controller - Microcontroller / Display board
Luke Weston, 2012
http://github.com/lukeweston/3DPrinterController
Released under the CERN Open Hardware License:
http://ohwr.org/cernohl
FT230X

Board: 2 copper layers, 49 parts (0 on the bottom side), 80 nets, no tracks yet.

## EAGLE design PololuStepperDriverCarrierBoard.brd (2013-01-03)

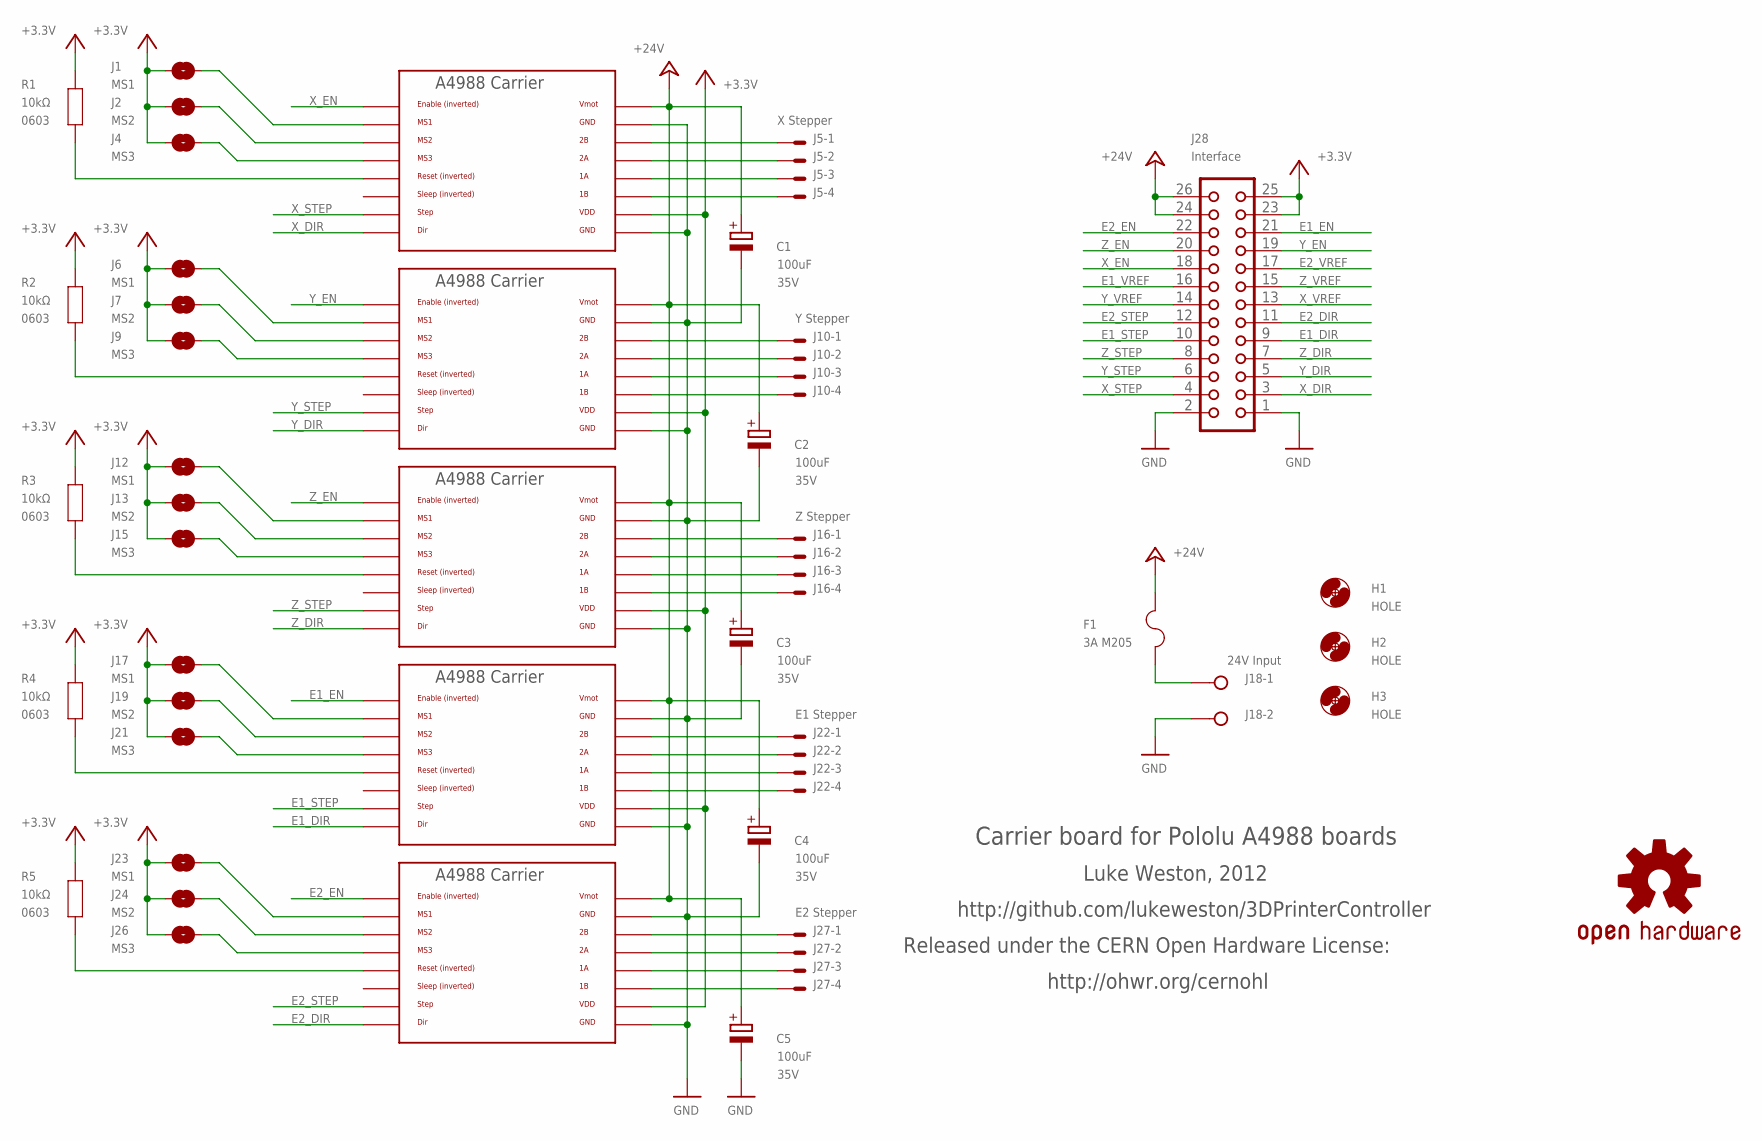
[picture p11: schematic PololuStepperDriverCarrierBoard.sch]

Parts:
C1, C2, C3, C4, C5: 100uF; E2,5-6; VOLTAGE 35V
F1: 3A M205; SHK20L
H1, H2, H3: HOLE; 3,2
J1, J6, J12, J17, J23: MS1; SJ
J2, J7, J13, J19, J24: MS2; SJ
J3, J8, J14, J20, J25: A4988BREAKOUT
J4, J9, J15, J21, J26: MS3; SJ
J5: X Stepper; 7395-04
J10: Y Stepper; 7395-04
J16: Z Stepper; 7395-04
J18: 24V Input; W237-132
J22: E1 Stepper; 7395-04
J27: E2 Stepper; 7395-04
J28: Interface; CON26L
R1, R2, R3, R4, R5: 10kΩ; 0603
SY1: OSHW-LOGOS; OSHW-LOGO-S

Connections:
+3V3: J1.1, J2.1, J3.VDD, J4.1, J6.1, J7.1, J8.VDD, J9.1, J12.1, J13.1, J14.VDD, J15.1, J17.1, J19.1, J20.VDD, J21.1, J23.1, J24.1, J25.VDD, J26.1, J28.23, J28.25, R1.1, R2.1, R3.1, R4.1, R5.1
+24V: C1.+, C2.+, C3.+, C4.+, C5.+, F1.2A (2), J3.VMOT, J8.VMOT, J14.VMOT, J20.VMOT, J25.VMOT, J28.24, J28.26
E1_DIR: J20.DIR, J28.9
E1_EN: J20.EN, J28.21
E1_STEP: J20.STEP, J28.10
E1_VREF: J28.16
E2_DIR: J25.DIR, J28.11
E2_EN: J25.EN, J28.22
E2_STEP: J25.STEP, J28.12
E2_VREF: J28.17
GND: C1.-, C2.-, C3.-, C4.-, C5.-, J3.GND, J3.GND@0 (GND), J8.GND, J8.GND@0 (GND), J14.GND, J14.GND@0 (GND), J18.2, J20.GND, J20.GND@0 (GND), J25.GND, J25.GND@0 (GND), J28.1, J28.2
unnamed: J8.RST, R2.2
unnamed: J3.2B, J5.1
unnamed: J3.1B, J5.4
unnamed: J3.1A, J5.3
unnamed: J3.2A, J5.2
unnamed: J8.2B, J10.1
unnamed: J8.1A, J10.3
unnamed: J8.2A, J10.2
unnamed: J8.1B, J10.4
unnamed: J14.2B, J16.1
unnamed: J14.1B, J16.4
unnamed: J14.1A, J16.3
unnamed: J14.2A, J16.2
unnamed: J20.2A, J22.2
unnamed: J20.2B, J22.1
unnamed: J20.1A, J22.3
unnamed: J20.1B, J22.4
unnamed: J25.2B, J27.1
unnamed: J25.2A, J27.2
unnamed: J25.1A, J27.3
unnamed: J25.1B, J27.4
unnamed: J3.RST, R1.2
unnamed: J8.MS3, J9.2
unnamed: J7.2, J8.MS2
unnamed: J3.MS3, J4.2
unnamed: J2.2, J3.MS2
unnamed: J1.2, J3.MS1
unnamed: J6.2, J8.MS1
unnamed: J14.RST, R3.2
unnamed: J14.MS3, J15.2
unnamed: J13.2, J14.MS2
unnamed: J12.2, J14.MS1
unnamed: J25.RST, R5.2
unnamed: J25.MS3, J26.2
unnamed: J24.2, J25.MS2
unnamed: J23.2, J25.MS1
unnamed: J20.RST, R4.2
unnamed: J20.MS3, J21.2
unnamed: J19.2, J20.MS2
unnamed: J17.2, J20.MS1
unnamed: F1.1A (1), J18.1
X_DIR: J3.DIR, J28.3
X_EN: J3.EN, J28.18
X_STEP: J3.STEP, J28.4
X_VREF: J28.13
Y_DIR: J8.DIR, J28.5
Y_EN: J8.EN, J28.19
Y_STEP: J8.STEP, J28.6
Y_VREF: J28.14
Z_DIR: J14.DIR, J28.7
Z_EN: J14.EN, J28.20
Z_STEP: J14.STEP, J28.8
Z_VREF: J28.15

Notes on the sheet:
Carrier board for Pololu A4988 boards
Luke Weston, 2012
http://github.com/lukeweston/3DPrinterController
Released under the CERN Open Hardware License:
http://ohwr.org/cernohl

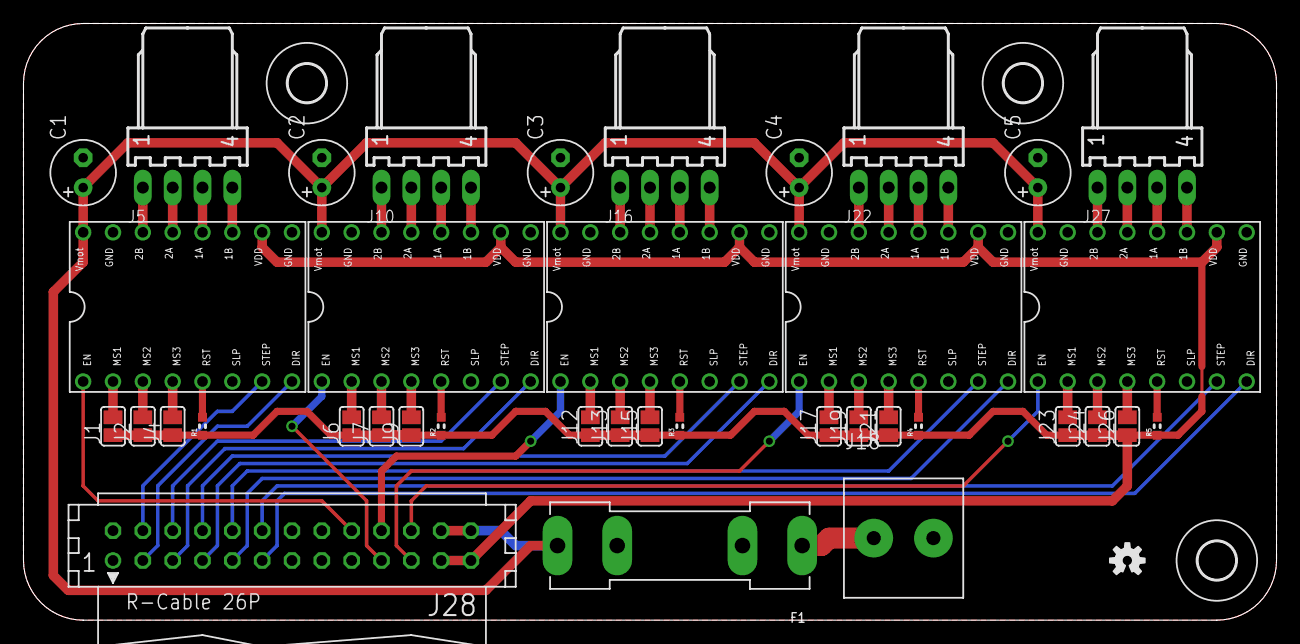
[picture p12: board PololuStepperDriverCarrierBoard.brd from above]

Board: 2 copper layers, 106.7 x 50.8 mm, 42 parts (0 on the bottom side), 59 nets.

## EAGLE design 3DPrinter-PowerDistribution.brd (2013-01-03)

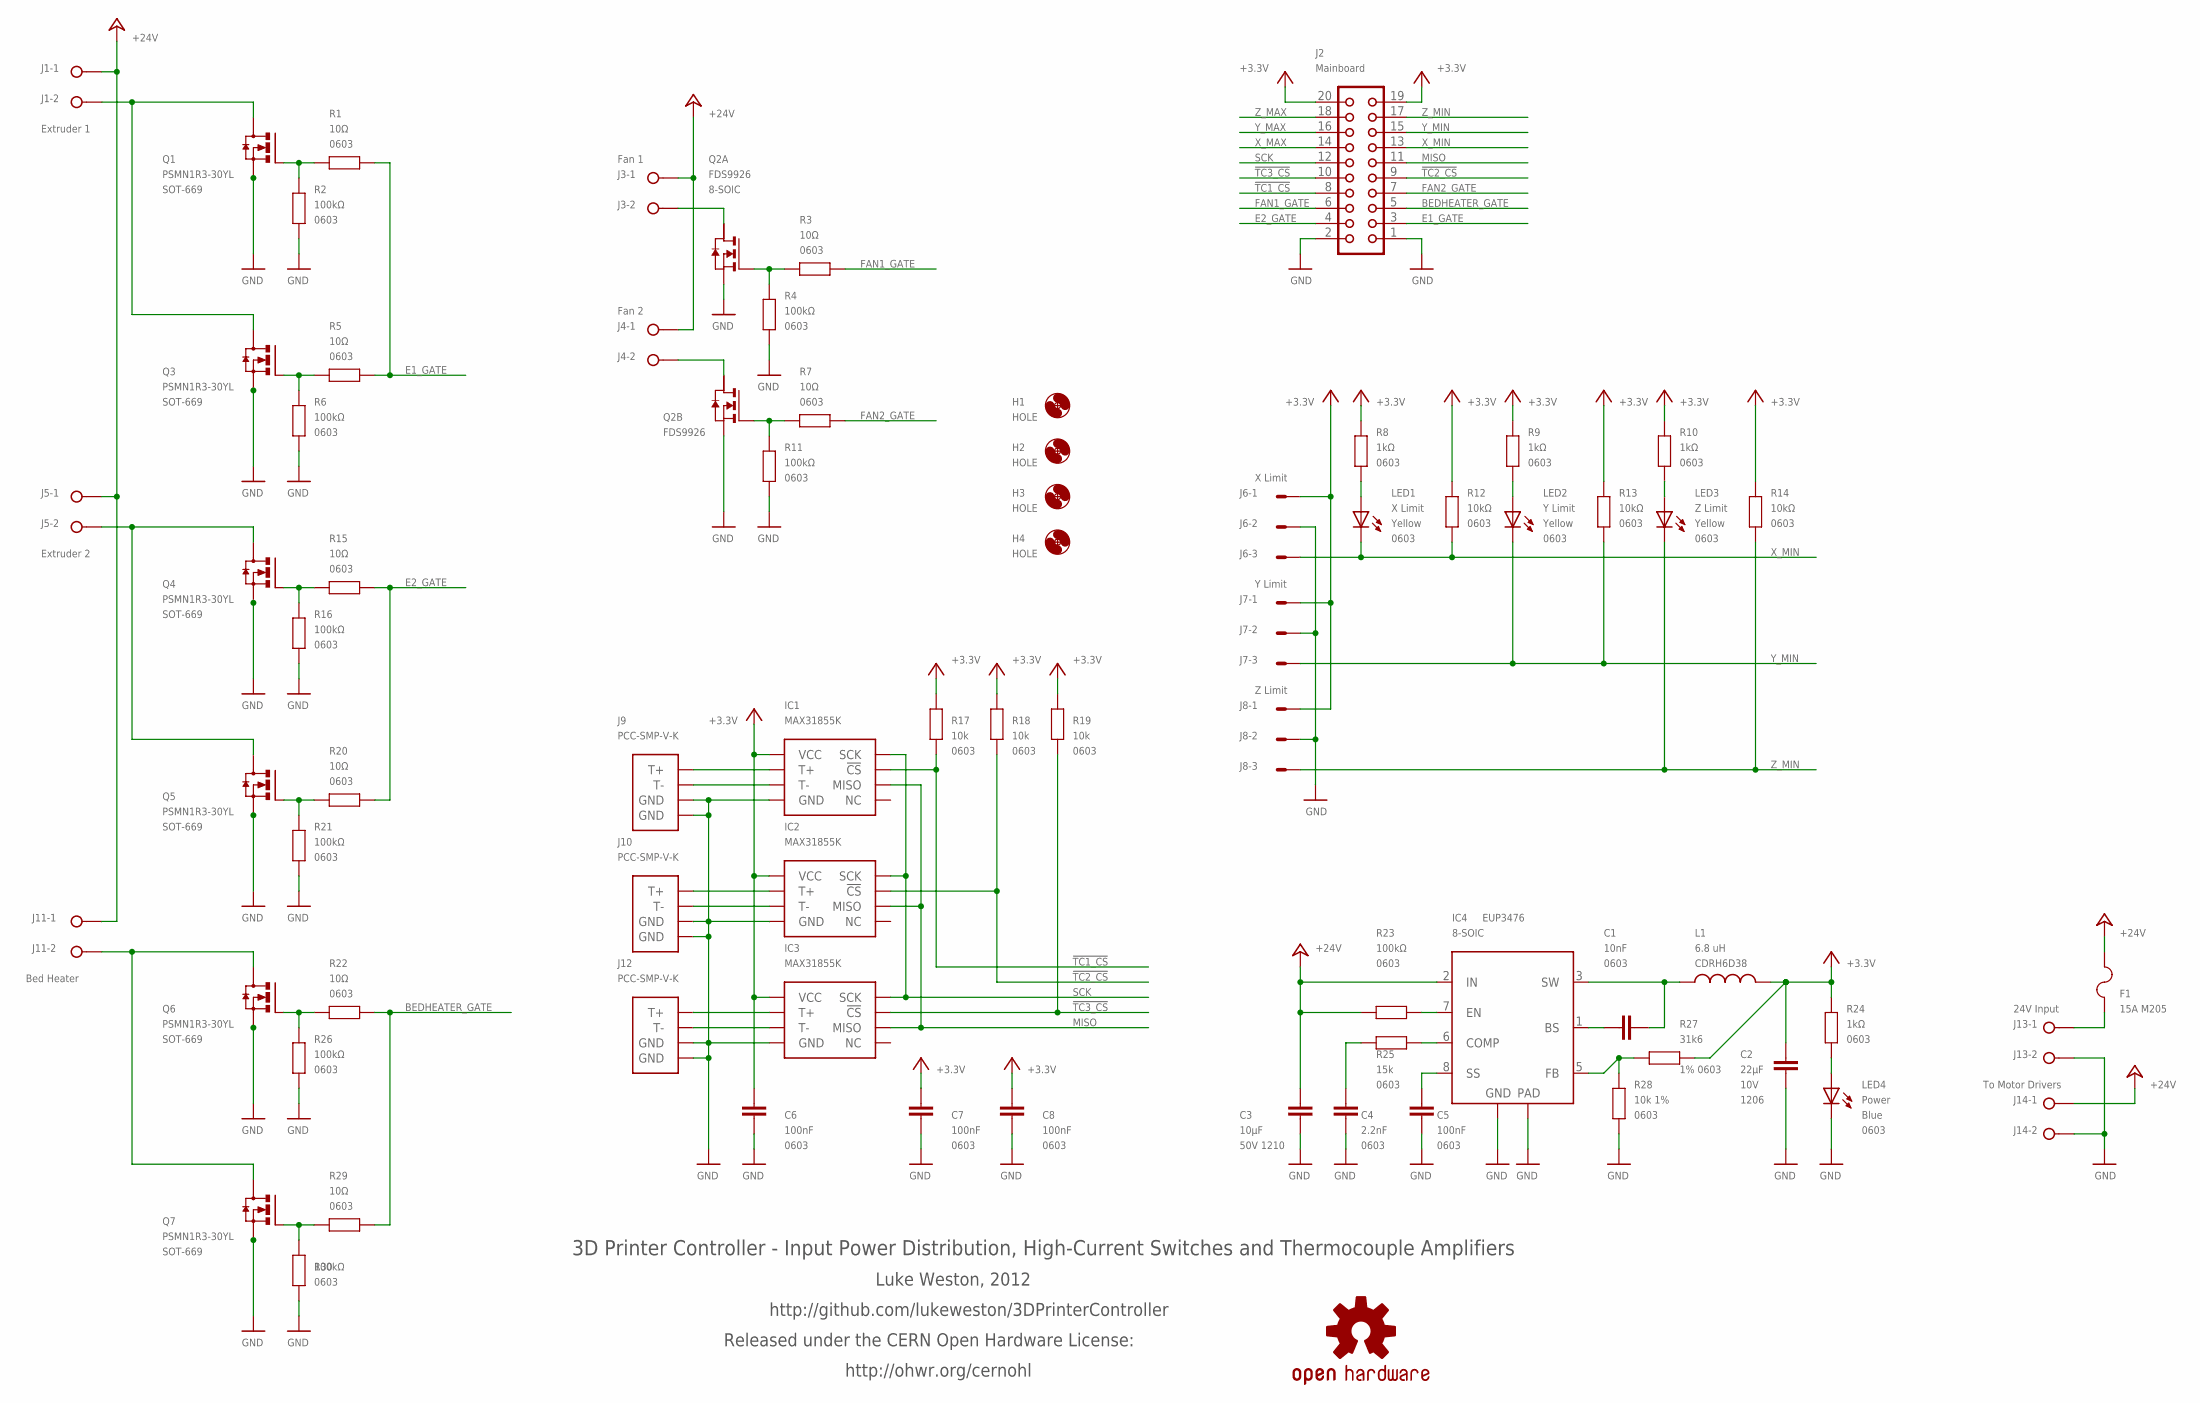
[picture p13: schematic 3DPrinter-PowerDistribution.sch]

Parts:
C1: 10nF; 0603
C2: 22µF; C1206K; VOLTAGE 10V
C3: 10µF; C1210K; VOLTAGE 50V 1210
C4: 2.2nF; 0603
C5, C6, C7, C8: 100nF; 0603
F1: 15A M205; SHK20L
H1, H2, H3, H4: HOLE; 3,2
IC1, IC2, IC3: MAX31855K; MCLENG_SOIC-8
IC4: EUP3476; SO08T
J1: Extruder 1; W237-132
J2: Mainboard; CON20L
J3: Fan 1; W237-132
J4: Fan 2; W237-132
J5: Extruder 2; W237-132
J6: X Limit; 7395-03
J7: Y Limit; 7395-03
J8: Z Limit; 7395-03
J9, J10, J12: PCC-SMP-V-K; MCLAUGHLINENG_TC_JACK
J11: Bed Heater; W237-132
J13: 24V Input; W237-132
J14: To Motor Drivers; W237-132
L1: 6.8 uH; CDRH
LED1: X Limit; LED-0603
LED2: Y Limit; LED-0603
LED3: Z Limit; LED-0603
LED4: Power; LED-0603
Q1, Q3, Q4, Q5, Q6, Q7: PSMN1R3-30YL; SOT669
Q2: FDS9926; SM8
R1, R3, R5, R7, R15, R20, R22, R29: 10Ω; 0603
R2, R4, R6, R11, R16, R21, R23, R26, R30: 100kΩ; 0603
R8, R9, R10, R24: 1kΩ; 0603
R12, R13, R14: 10kΩ; 0603
R17, R18, R19: 10k; 0603
R25: 15k; 0603
R27: 31k6; 0603
R28: 10k 1%; 0603
SY: OSHW-LOGOS; OSHW-LOGO-S

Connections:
!TC1_CS: IC1.CS (!CS), J2.8, R17.2
!TC2_CS: IC2.CS (!CS), J2.9, R18.2
!TC3_CS: IC3.CS (!CS), J2.10, R19.2
+3.3V: C2.1, C6.1, C7.1, C8.1, IC1.VCC, IC2.VCC, IC3.VCC, J2.19, J2.20, J6.1, J7.1, J8.1, L1.2, R8.1, R9.1, R10.1, R12.1, R13.1, R14.1, R17.1, R18.1, R19.1, R24.1, R27.1
+24V: C3.1, F1.2A (2), IC4.2 (IN), J1.1, J3.1, J4.1, J5.1, J11.1, J14.1, R23.2
BEDHEATER_GATE: J2.5, R22.1, R29.1
E1_GATE: J2.3, R1.1, R5.1
E2_GATE: J2.4, R15.1, R20.1
FAN1_GATE: J2.6, R3.1
FAN2_GATE: J2.7, R7.1
GND: C2.2, C3.2, C4.1, C5.1, C6.2, C7.2, C8.2, IC1.GND, IC2.GND, IC3.GND, IC4.4 (GND), IC4.9 (TGND), J2.1, J2.2, J6.2, J7.2, J8.2, J9.P$1 (GND), J9.P$2 (GND), J10.P$1 (GND), J10.P$2 (GND), J12.P$1 (GND), J12.P$2 (GND), J13.2, J14.2, LED4.C, Q1.1 (S), Q1.2 (S), Q1.3 (S), Q2.1 (S), Q2.3 (S), Q3.1 (S), Q3.2 (S), Q3.3 (S), Q4.1 (S), Q4.2 (S), Q4.3 (S), Q5.1 (S), Q5.2 (S), Q5.3 (S), Q6.1 (S), Q6.2 (S), Q6.3 (S), Q7.1 (S), Q7.2 (S), Q7.3 (S), R2.2, R4.2, R6.2, R11.2, R16.2, R21.2, R26.2, R28.2, R30.2
J5: J11.2, Q6.MB (D), Q7.MB (D)
MISO: IC1.SO (MISO), IC2.SO (MISO), IC3.SO (MISO), J2.11
unnamed: Q3.4 (G), R5.2, R6.1
unnamed: J1.2, Q1.MB (D), Q3.MB (D)
unnamed: Q4.4 (G), R15.2, R16.1
unnamed: J5.2, Q4.MB (D), Q5.MB (D)
unnamed: Q5.4 (G), R20.2, R21.1
unnamed: F1.1A (1), J13.1
unnamed: Q6.4 (G), R22.2, R26.1
unnamed: IC1.T+, J9.T+
unnamed: Q7.4 (G), R29.2, R30.1
unnamed: J3.2, Q2.5 (D)
unnamed: IC1.T-, J9.T-
unnamed: J4.2, Q2.7 (D)
unnamed: Q2.4 (G), R3.2, R4.1
unnamed: Q2.2 (G), R7.2, R11.1
unnamed: LED1.A, R8.2
unnamed: LED2.A, R9.2
unnamed: LED3.A, R10.2
unnamed: LED4.A, R24.2
unnamed: Q1.4 (G), R1.2, R2.1
unnamed: IC3.T-, J12.T-
unnamed: IC3.T+, J12.T+
unnamed: IC2.T-, J10.T-
unnamed: IC2.T+, J10.T+
unnamed: IC4.7 (EN), R23.1
unnamed: C1.1, IC4.3 (SW), L1.1
unnamed: C1.2, IC4.1 (BS)
unnamed: C4.2, R25.2
unnamed: IC4.6 (COMP), R25.1
unnamed: C5.2, IC4.8 (SS)
unnamed: IC4.5 (FB), R27.2, R28.1
SCK: IC1.SCK, IC2.SCK, IC3.SCK, J2.12
X_MAX: J2.14
X_MIN: J2.13, J6.3, LED1.C, R12.2
Y_MAX: J2.16
Y_MIN: J2.15, J7.3, LED2.C, R13.2
Z_MAX: J2.18
Z_MIN: J2.17, J8.3, LED3.C, R14.2

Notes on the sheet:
3D Printer Controller - Input Power Distribution, High-Current Switches and Thermocouple Amplifiers
Luke Weston, 2012
http://github.com/lukeweston/3DPrinterController
Released under the CERN Open Hardware License:
http://ohwr.org/cernohl

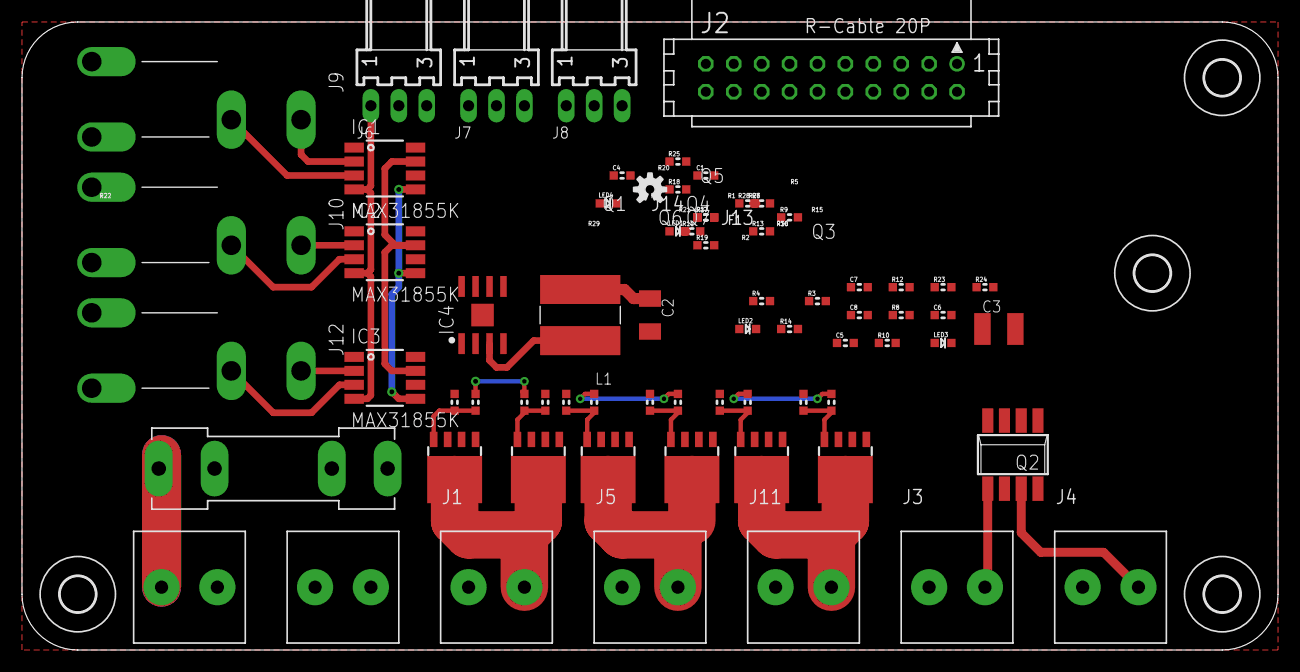
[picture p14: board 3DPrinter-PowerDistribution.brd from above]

Board: 2 copper layers, 114.3 x 57.1 mm, 74 parts (0 on the bottom side), 47 nets.
